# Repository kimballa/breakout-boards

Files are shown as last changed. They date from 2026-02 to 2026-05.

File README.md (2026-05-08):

SMD breakout boards
===================

This repo contains Kicad projects and camera-ready gerber files for panelized SMD component breakout boards.
The design of these breakout boards emphasizes narrow breakouts that "waste" fewer rows of pins in breadboards,
at the expense of slightly longer breakout boards that "overhang"  some number of pins to the left or right
of the actual pin header. In most cases, breakout boards are the same width as a comparable THT DIP
component. Others span the gap in the middle of a breadboard plus only a single extra row (beyond the two rows
necessary for the pin headers).

Panels are designed to fit within the 100x100 mm size for a JLCPCB economy "special price" build. In many
cases, the 5 panel minimum will still result in a supply of breakout boards that will last even ambitious
hobbyists a long while. If you require more, the low marginal cost of increasing to 10 or 20 panels likely 
outcompetes the cost of making larger panels that can be ordered at qty=5.

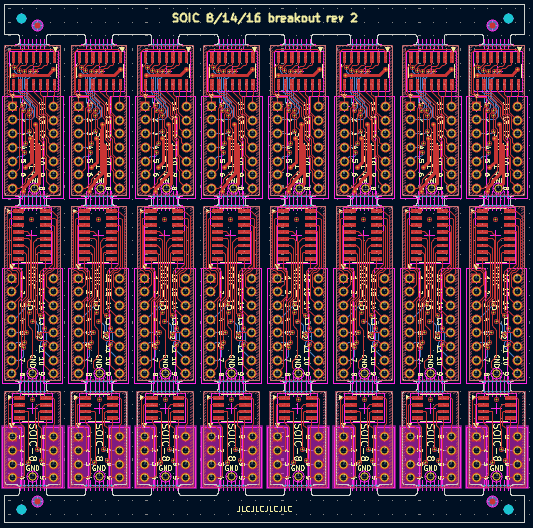
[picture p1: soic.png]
SOIC breakout board panel PCB CAD drawing SOIC breakout board panel


Directory structure
-------------------

There are a few subdirectories that each contain one or more breakout boards:

* `soic` - Two panels with a mix of SOIC-8, -14, and -16 breakouts, and TSSOP-8, -14, and -16
  breakouts.
* `soic-dw` - A panel with a mix of "widebody" (Texas Instruments drawing "DW") SOIC-16 and
  SOIC-20 breakouts
* `sot-23` - Two panels of SOT-23-6 and SOT-23-8 breakouts
* `qfn-20` - A non-panelized QFN-20 breakout board
* `so-8-fet` - Panelized SO-8 / 5050 FET / Power-TDFN footprint for SMD power MOSFETs.
  Uses NXP's "universal 5060 footprint" for maximum adaptability.
* `micromatch-20` - a separate (non-panelized) breakout for the MicroMaTcH 20 pin connector 

All panels were created with KiKit. Each "base" directory contains Kicad project and PCB layout(s)
for singleton breakout boards. Panelized PCBs are in a subdirectory called `out` or `panelized`.

* The SOT-23 and SO-8-FET breakout boards were made using the KiKit GUI from the plugin. To regenerate, load the JSON config
  file to load the appropriate settings, and identify the input kicad_pcb and target kicad_pcb files.
* The SOIC / TSSOP and SOIC-DW breakout boards were made using the KiKit API. Each directory has a script
  called `panelize.py`. Open a KiCad Command Line terminal and run `python panelize.py` in the directory.
  The output will be generated in the `out/` subdirectory. The same `panelize.py` script in the `soic` 
  directory is used for generating SOIC or TSSOP panel, but some settings at the top of the script must
  be edited to switch from one to the other.

Gerber files are available in the `rtm/` subdirectory of each subproject. If multiple subdirectories exist
within `rtm`, choose the highest-numbered version to get the latest Gerbers.

Ordering breakout panels
------------------------

Zip up the gerber (and .drl) files in a given rtm directory and upload it to JLCPCB.com. The panel size and "2 layers" 
should be auto-selected. Choose "panel by customer", input the number of unique designs in the board file
(3 for SOIC and TSSOP; 2 for SOIC-DW, 1 for SOT-23-6 and SOT-23-8), and the number of rows and columns.

You should also probably select "remove order number", and your choice of HASL or HASL Lead-free surface
finishing. (You could choose ENIG but it will be overkill, *unless you are ordering the QFN*, in which case
it is mandatory.)

The default number of each panel you order is 5; you can also dial this up as-needed. 

Assembly
--------

Arrange your SMT component on the board with pin 1 closest to the dot or triangular arrow mark on the board
in the SMT area. Tack down one pin with your soldering iron, then do the rest. Clip pin headers to length
and place them in the breadboard, then seat the breakout board on top. Solder from above, lightly pressing 
the board down onto the seating plane of the pin headers.  

Any 2.54mm-pitch pin headers will do, but if you're looking for a specific part to order, Amphenol ICC (FCI)
part number `68000-400HLF` is a quality cuttable pin header strip, orderable from Mouser, Digikey, and likely
many others. Order qty is the number of connected pins you'd like; I typically buy by the 500 or so.

Where possible, a "ground plane" is provided on many breakout boards. A separate 1.1mm hole is available
in the middle of the board. After attaching the chip and the pin headers, solder a short piece of jumper 
wire from the hole to the top of whichever pin indicates GND (likely the one in the front right corner, 
but not always; check your datasheet).

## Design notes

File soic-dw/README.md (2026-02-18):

SOIC-DW (Wide) Breakouts
========================

Breakout boards for {16, 20}-pin wide-body SOIC (1.27mm pitch) ICs that fit in standard pin
alignment on a breadboard.

The IC itself sits to the side of the pin headers rather than between them, to achieve a
narrow breakout board profile (12.8mm) that straddles only one extra row of pins on one
or the other side of the breadboard centerline.

A separate through-hole exists in the SOIC-16 board, connected to the ground plane. Solder a
resistor leg or other thin wire from the `GND` hole to top of the header pin that
represents ground for the IC. (Or leave floating if there is no appropriate ground pin for
the IC.)

The file name (SOIC-DW) derives from Texas Instruments' name for the wide SOIC package type.

## Gerber files

The latest gerber files for submitting to a board fab are in the `rtm/` directory.

If submitting to JLCPCB, select 'panel by customer', 'number of designs' = 2.

## Panelization

The main project file includes one of each representative breakout board. Panels with 8x
SOIC-16 and 6x SOIC-20 format were generated using KiKit. If you change the main PCB
CAD file, you should then open a KiCad Command Prompt in this directory and run `python
panelize.py`. You can edit `panelize.py` first to set variables related to the output file
to generate.

### Script notes:

The current layout is intended to fit in the 100x100 mm area that offers the best
deal for JLCPCB, but you can extend taller or wider if desired.

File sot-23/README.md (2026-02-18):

SOT-23 breakouts
================

This directory contains kicad project files and camera-ready gerber files for SOT-23-6 and
SOT-23-8 breakout board PCBs.

Order PCBs
----------

Look in the `panelized/rtm/` directory and select the subdirectory with the highest
version number.  There are separate subdirectories in there for SOT-23-6 and SOT-23-8
breakout boards. Take all the files in one of those subdirectories (gerber files and
Excellon drill files) and zip them together. 

Order PCBs from jlcpcb.com:
* upload the zip file
* Set PCB Qty as you desire
* Panel By Customer
  * SOT-23-6: 10 cols, 6 rows
  * SOT-23-8: 7 cols, 6 rows
* Surface Finish: HASL (with lead) or LeadFree HASL as you desire
* All other options as-default.

To adjust board layouts
-----------------------

There is a source schematic which was used to create the sot-23 (6) and sot-23-8 kicad_pcb
files.  The schematic contains both breakouts; half of this was deleted on each PCB,
leaving each kicad_pcb file with a single sot-23-6 or sot-23-8 breakout. 

The panel PCBs in the `panelized/` subdirectory were derived from these using the KiKit
panelization plugin. JSON config files for each board are in the panelized/ directory and
can be imported into the KiKit configuration dialog to reproduce the same settings used to
generate the current panels.

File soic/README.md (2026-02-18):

SOIC Breakouts
==============

Breakout boards for {8, 14, 16}-pin SOIC and TSSOP ICs
that fit in a standard DIP width on a breadboard.

The IC itself sits to the side of the pin headers rather than between them, to achieve a
narrow breakout board profile (10.3mm) that does not straddle an extra row of pins on one
or the other side of the breadboard centerline. 

A separate through-hole exists in each SOIC board, connected to the ground plane. Solder a
resistor leg or other thin wire from the `GND` hole to top of the header pin that
represents ground for the IC. (Or leave floating if there is no appropriate ground pin for
the IC.)

## Gerber files

The latest gerber files for submitting to a board fab are in the `rtm/` directory.

If submitting to JLCPCB, select 'panel by customer', 'number of designs' = 3. 

## Panelization

The main project file includes one of each representative breakout board. Panels with 8 of
each SOIC or 8 of each TSSOP format were generated using KiKit. If you change the main PCB
CAD file, you should then open a KiCad Command Prompt in this directory and run `python
panelize.py`. You can edit `panelize.py` first to set variables related to the output file
to generate. You need to edit the script to select B1-B3 (SOIC), or B4-B6 (TSSOP boards)
for panelization.

### Script notes:

The current layout (n=8) is intended to fit in the 100x100 mm area that offers the best
deal for JLCPCB, but you can extend wider. The script would need to be modified to include
more than one row of each board. The script also assumes that all boards are the same
width, and may misalign columns if not accounted-for in any future modification that
changes some of the board widths.

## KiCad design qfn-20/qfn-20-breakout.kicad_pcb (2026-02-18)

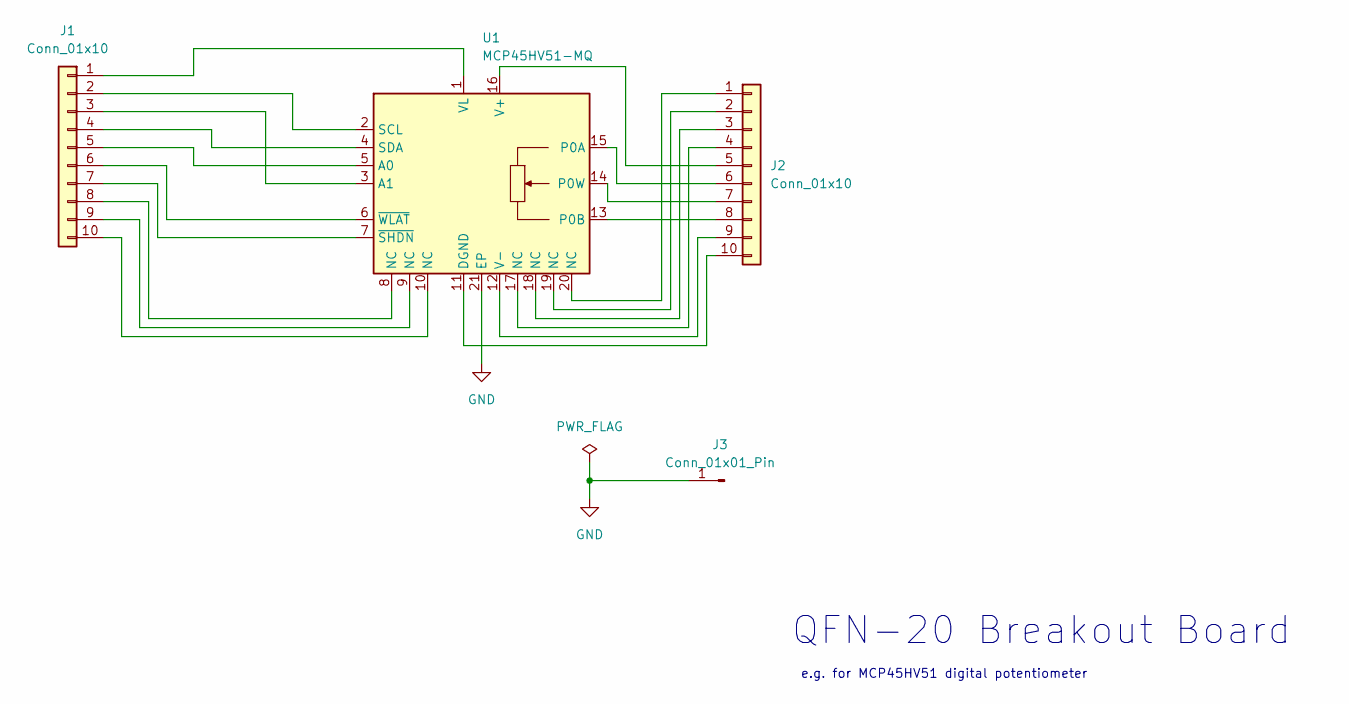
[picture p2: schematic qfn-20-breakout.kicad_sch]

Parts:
J1, J2: Conn_01x10; PinHeader_1x10_P2.54mm_Vertical
J3: Conn_01x01_Pin; TP_HeaderPin_P2.54mm_round
U1: MCP45HV51-MQ; TI-QFN-20-1EP_5x5mm_P0.65mm_EP3.35x3.35mm

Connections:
GND: J3.1, U1.21 (EP)
unnamed: J1.1, U1.1 (VL)
unnamed: J1.2, U1.2 (SCL)
unnamed: J1.3, U1.3 (A1)
unnamed: J1.4, U1.4 (SDA)
unnamed: J1.5, U1.5 (A0)
unnamed: J1.6, U1.6 (~WLAT)
unnamed: J1.7, U1.7 (~SHDN)
unnamed: J1.8, U1.8 (NC)
unnamed: J1.9, U1.9 (NC)
unnamed: J1.10, U1.10 (NC)
unnamed: J2.1, U1.20 (NC)
unnamed: J2.2, U1.19 (NC)
unnamed: J2.3, U1.18 (NC)
unnamed: J2.4, U1.17 (NC)
unnamed: J2.5, U1.16 (V+)
unnamed: J2.6, U1.15 (P0A)
unnamed: J2.7, U1.14 (P0W)
unnamed: J2.8, U1.13 (P0B)
unnamed: J2.9, U1.12 (V-)
unnamed: J2.10, U1.11 (DGND)

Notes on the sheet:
e.g. for MCP45HV51 digital potentiometer
QFN-20 Breakout Board

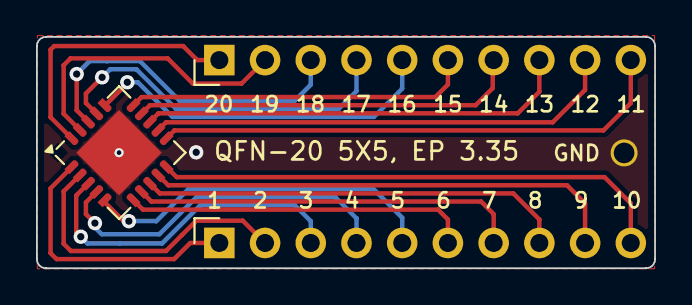
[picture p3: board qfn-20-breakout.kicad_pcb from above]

Board: 2 copper layers, 34.3 x 12.9 mm, 4 parts (0 on the bottom side), 21 nets.

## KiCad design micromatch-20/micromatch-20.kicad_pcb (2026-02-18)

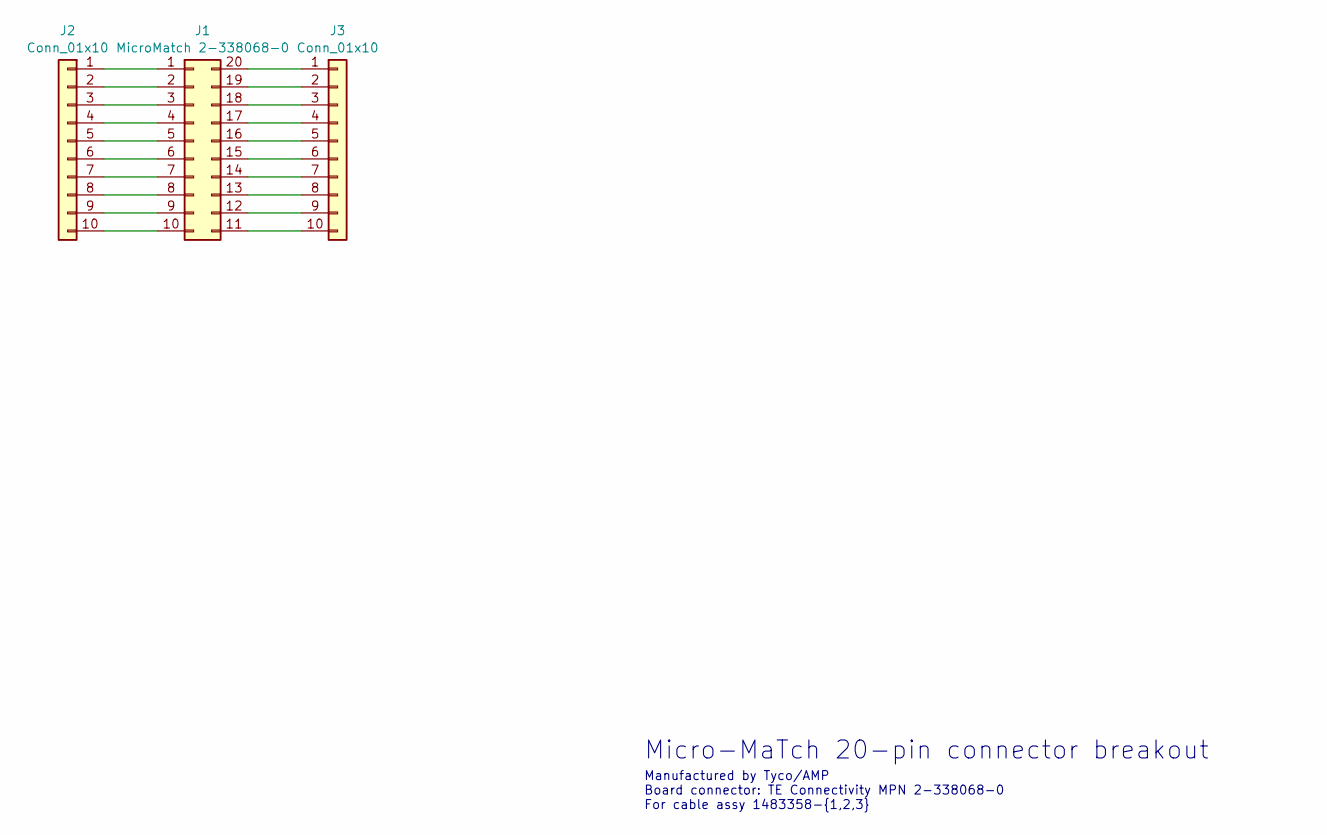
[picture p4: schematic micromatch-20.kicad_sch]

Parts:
J1: MicroMatch 2-338068-0; MicroMatch_20_F_Socket_2x10
J2, J3: Conn_01x10; PinHeader_1x10_P2.54mm_Vertical

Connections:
unnamed: J1.1, J2.1
unnamed: J1.2, J2.2
unnamed: J1.3, J2.3
unnamed: J1.4, J2.4
unnamed: J1.5, J2.5
unnamed: J1.6, J2.6
unnamed: J1.7, J2.7
unnamed: J1.8, J2.8
unnamed: J1.9, J2.9
unnamed: J1.10, J2.10
unnamed: J1.11, J3.10
unnamed: J1.12, J3.9
unnamed: J1.13, J3.8
unnamed: J1.14, J3.7
unnamed: J1.15, J3.6
unnamed: J1.16, J3.5
unnamed: J1.17, J3.4
unnamed: J1.18, J3.3
unnamed: J1.19, J3.2
unnamed: J1.20, J3.1

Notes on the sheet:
Micro-MaTch 20-pin connector breakout
Manufactured by Tyco/AMP Board connector: TE Connectivity MPN 2-338068-0 For cable assy 1483358-{1,2,3}

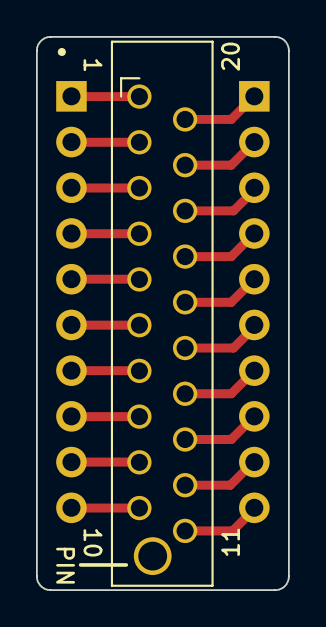
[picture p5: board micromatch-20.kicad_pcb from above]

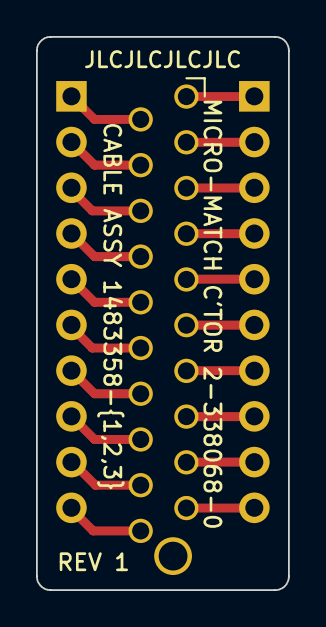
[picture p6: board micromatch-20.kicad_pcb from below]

Board: 2 copper layers, 14.0 x 30.7 mm, 3 parts (2 on the bottom side), 20 nets.

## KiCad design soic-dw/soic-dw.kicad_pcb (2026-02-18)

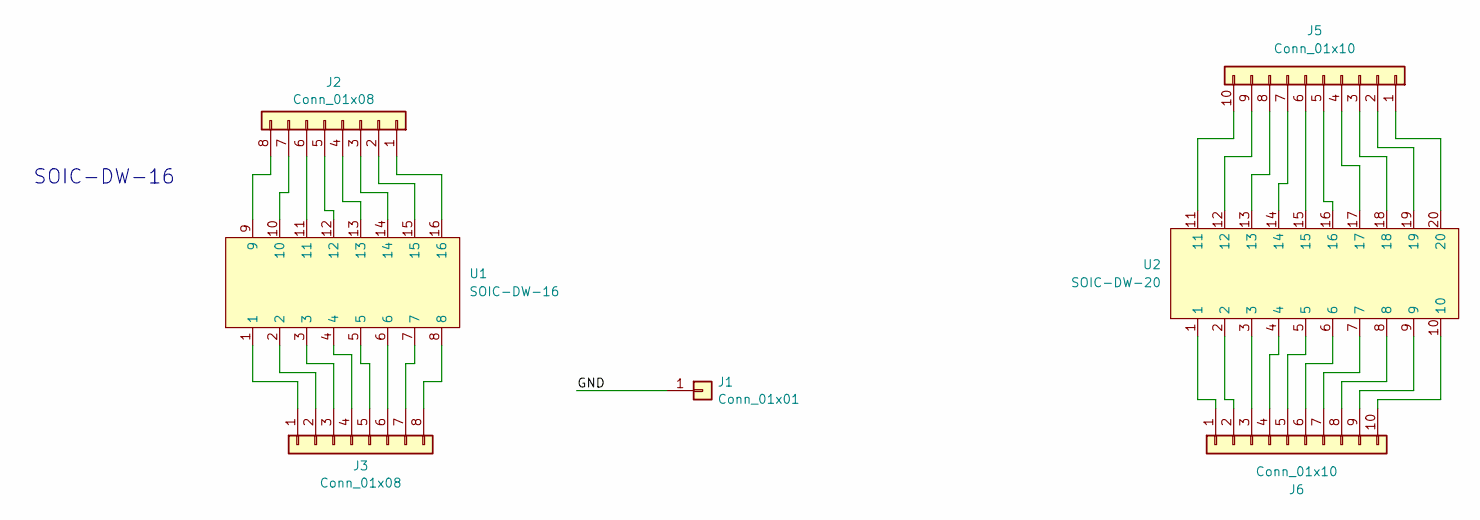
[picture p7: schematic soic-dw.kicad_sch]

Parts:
J1: Conn_01x01; TP_HeaderPin_P2.54mm_round
J2, J3: Conn_01x08; PinHeader_1x08_P2.54mm_Vertical
J5, J6: Conn_01x10; PinHeader_1x10_P2.54mm_Vertical
U1: SOIC-DW-16; TI_SOIC_DW0016A_MinSilk
U2: SOIC-DW-20; TI_SOIC_DW0020A

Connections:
/GND: J1.1
unnamed: J2.1, U1.16
unnamed: J2.2, U1.15
unnamed: J2.3, U1.14
unnamed: J2.4, U1.13
unnamed: J2.5, U1.12
unnamed: J2.6, U1.11
unnamed: J2.7, U1.10
unnamed: J2.8, U1.9
unnamed: J3.1, U1.1
unnamed: J3.2, U1.2
unnamed: J3.3, U1.3
unnamed: J3.4, U1.4
unnamed: J3.5, U1.5
unnamed: J3.6, U1.6
unnamed: J3.7, U1.7
unnamed: J3.8, U1.8
unnamed: J5.1, U2.20
unnamed: J5.2, U2.19
unnamed: J5.3, U2.18
unnamed: J5.4, U2.17
unnamed: J5.5, U2.16
unnamed: J5.6, U2.15
unnamed: J5.7, U2.14
unnamed: J5.8, U2.13
unnamed: J5.9, U2.12
unnamed: J5.10, U2.11
unnamed: J6.1, U2.1
unnamed: J6.2, U2.2
unnamed: J6.3, U2.3
unnamed: J6.4, U2.4
unnamed: J6.5, U2.5
unnamed: J6.6, U2.6
unnamed: J6.7, U2.7
unnamed: J6.8, U2.8
unnamed: J6.9, U2.9
unnamed: J6.10, U2.10

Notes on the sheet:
SOIC-DW-16

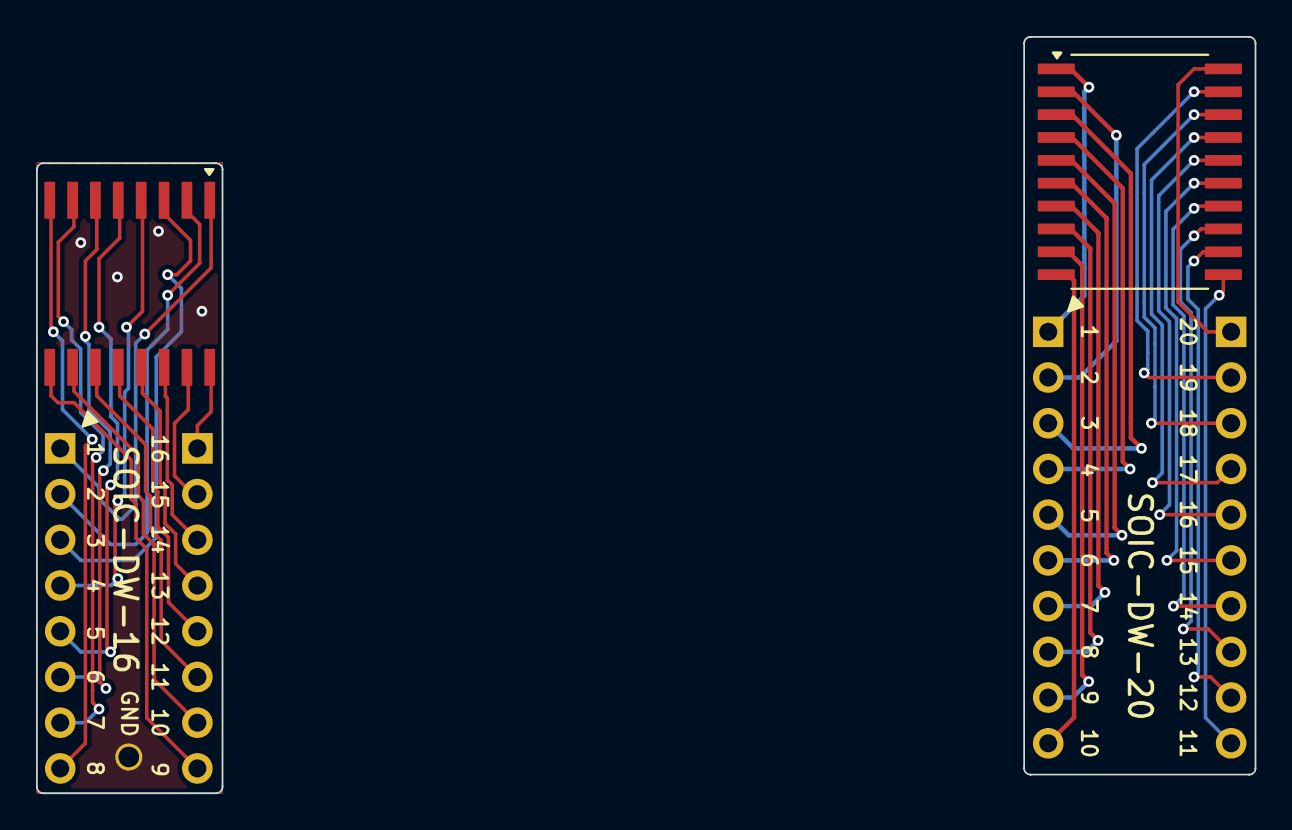
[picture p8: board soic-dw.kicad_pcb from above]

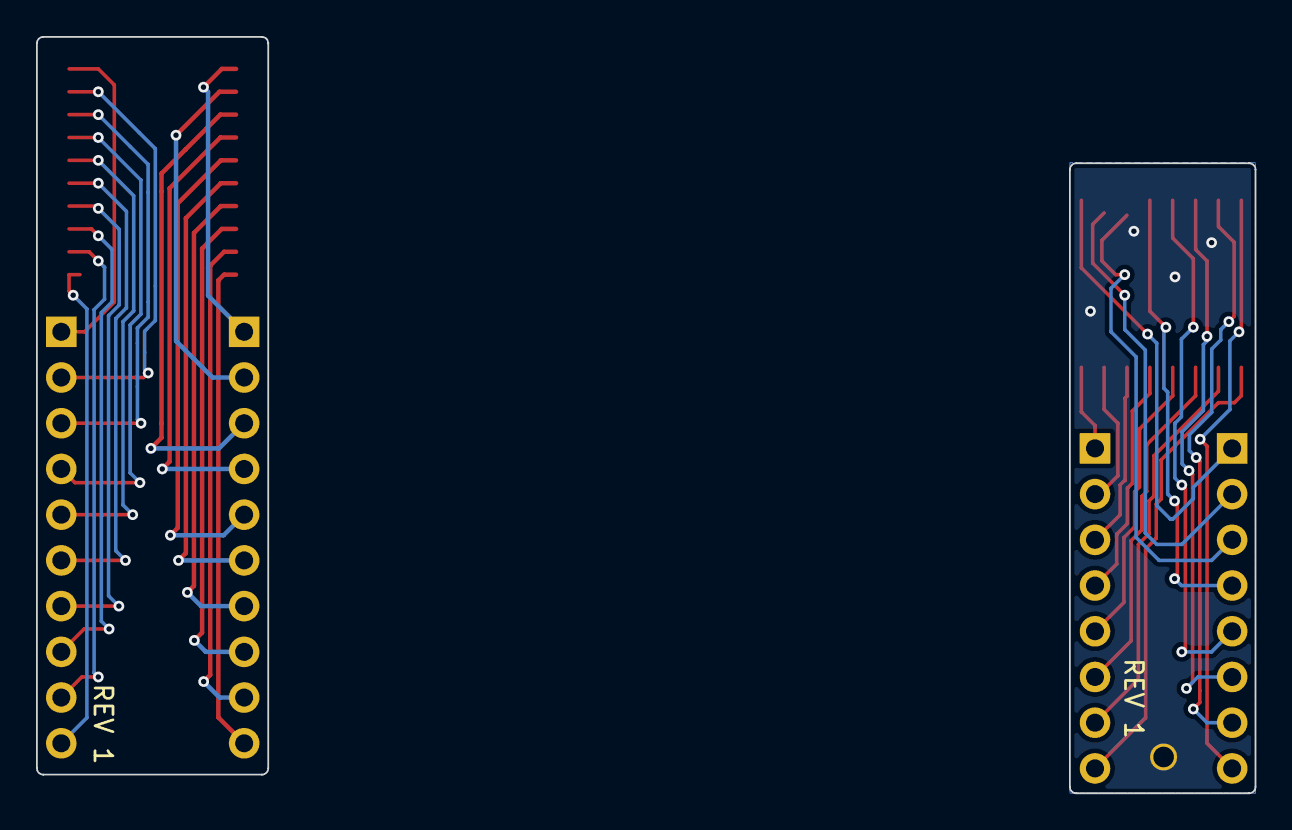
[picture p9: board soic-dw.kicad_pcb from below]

Board: 2 copper layers, 67.7 x 42.0 mm, 9 parts (4 on the bottom side), 36 nets.

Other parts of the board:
B1, B2: Board

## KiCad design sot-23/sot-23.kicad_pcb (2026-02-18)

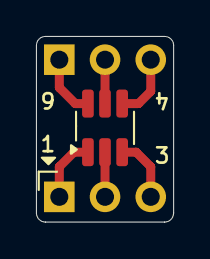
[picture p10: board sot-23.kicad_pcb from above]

Board: 2 copper layers, 7.6 x 10.3 mm, 3 parts (0 on the bottom side), 6 nets.

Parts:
J1, J2: Conn_01x03; PinHeader_1x03_P2.54mm_Vertical
Q1: BCM847DS; SOT-23-6_Handsoldering

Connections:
unnamed: J1.1, Q1.1 (E1)
unnamed: J1.2, Q1.2 (B1)
unnamed: J1.3, Q1.3 (C2)
unnamed: J2.1, Q1.6 (C1)
unnamed: J2.2, Q1.5 (B2)
unnamed: J2.3, Q1.4 (E2)

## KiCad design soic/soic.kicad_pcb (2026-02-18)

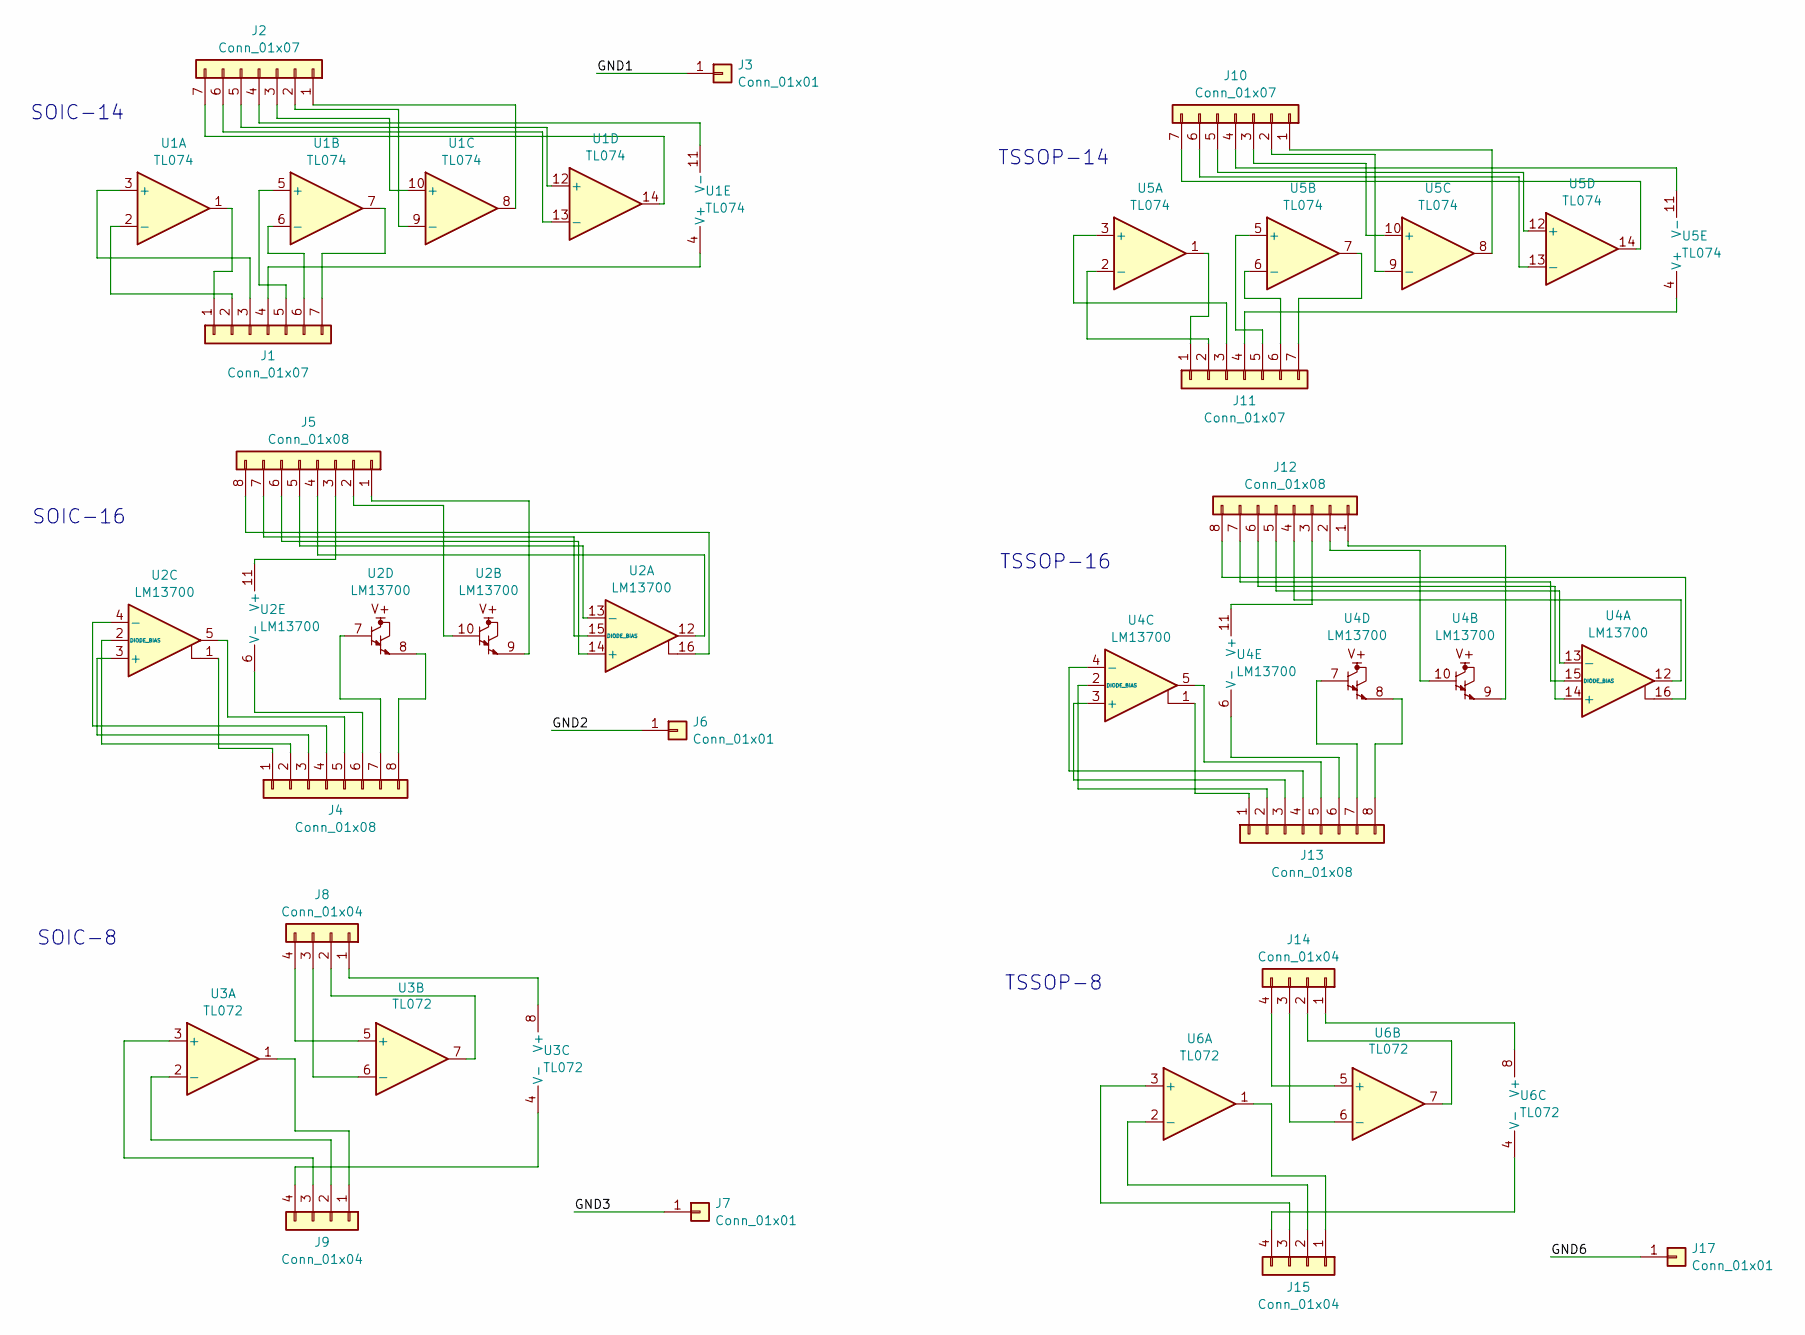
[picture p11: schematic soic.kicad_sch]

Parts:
J1, J2, J10, J11: Conn_01x07; PinHeader_1x07_P2.54mm_Vertical
J3, J6, J7, J17: Conn_01x01; TP_HeaderPin_P2.54mm_round
J4, J5, J12, J13: Conn_01x08; PinHeader_1x08_P2.54mm_Vertical
J8, J9, J14, J15: Conn_01x04; PinHeader_1x04_P2.54mm_Vertical
U1: TL074; TI_SOIC_D_R-PDSO-G14
U2: LM13700; TI_SOIC_D_R-PDSO-16
U3: TL072; TI_SOIC_D_R-PDSO-8
U4: LM13700; TSSOP-16_4.4x5mm_P0.65mm
U5: TL074; TI_TSSOP_PW0014A
U6: TL072; TI_TSSOP_PW0008A

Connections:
/GND1: J3.1
/GND2: J6.1
/GND3: J7.1
/GND6: J17.1
unnamed: J1.1, U1.1
unnamed: J1.2, U1.2 (-)
unnamed: J1.3, U1.3 (+)
unnamed: J1.4, U1.4 (V+)
unnamed: J1.5, U1.5 (+)
unnamed: J1.6, U1.6 (-)
unnamed: J1.7, U1.7
unnamed: J2.1, U1.8
unnamed: J2.2, U1.9 (-)
unnamed: J2.3, U1.10 (+)
unnamed: J2.4, U1.11 (V-)
unnamed: J2.5, U1.12 (+)
unnamed: J2.6, U1.13 (-)
unnamed: J2.7, U1.14
unnamed: J4.1, U2.1
unnamed: J4.2, U2.2 (DIODE_BIAS)
unnamed: J4.3, U2.3 (+)
unnamed: J4.4, U2.4 (-)
unnamed: J4.5, U2.5
unnamed: J4.6, U2.6 (V-)
unnamed: J4.7, U2.7
unnamed: J4.8, U2.8
unnamed: J5.1, U2.9
unnamed: J5.2, U2.10
unnamed: J5.3, U2.11 (V+)
unnamed: J5.4, U2.12
unnamed: J5.5, U2.13 (-)
unnamed: J5.6, U2.14 (+)
unnamed: J5.7, U2.15 (DIODE_BIAS)
unnamed: J5.8, U2.16
unnamed: J8.1, U3.8 (V+)
unnamed: J8.2, U3.7
unnamed: J8.3, U3.6 (-)
unnamed: J8.4, U3.5 (+)
unnamed: J9.1, U3.1
unnamed: J9.2, U3.2 (-)
unnamed: J9.3, U3.3 (+)
unnamed: J9.4, U3.4 (V-)
unnamed: J10.1, U5.8
unnamed: J10.2, U5.9 (-)
unnamed: J10.3, U5.10 (+)
unnamed: J10.4, U5.11 (V-)
unnamed: J10.5, U5.12 (+)
unnamed: J10.6, U5.13 (-)
unnamed: J10.7, U5.14
unnamed: J11.1, U5.1
unnamed: J11.2, U5.2 (-)
unnamed: J11.3, U5.3 (+)
unnamed: J11.4, U5.4 (V+)
unnamed: J11.5, U5.5 (+)
unnamed: J11.6, U5.6 (-)
unnamed: J11.7, U5.7
unnamed: J12.1, U4.9
unnamed: J12.2, U4.10
unnamed: J12.3, U4.11 (V+)
unnamed: J12.4, U4.12
unnamed: J12.5, U4.13 (-)
unnamed: J12.6, U4.14 (+)
unnamed: J12.7, U4.15 (DIODE_BIAS)
unnamed: J12.8, U4.16
unnamed: J13.1, U4.1
unnamed: J13.2, U4.2 (DIODE_BIAS)
unnamed: J13.3, U4.3 (+)
unnamed: J13.4, U4.4 (-)
unnamed: J13.5, U4.5
unnamed: J13.6, U4.6 (V-)
unnamed: J13.7, U4.7
unnamed: J13.8, U4.8
unnamed: J14.1, U6.8 (V+)
unnamed: J14.2, U6.7
unnamed: J14.3, U6.6 (-)
unnamed: J14.4, U6.5 (+)
unnamed: J15.1, U6.1
unnamed: J15.2, U6.2 (-)
unnamed: J15.3, U6.3 (+)
unnamed: J15.4, U6.4 (V-)

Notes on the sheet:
SOIC-14
TSSOP-8
SOIC-8
TSSOP-14
SOIC-16
TSSOP-16

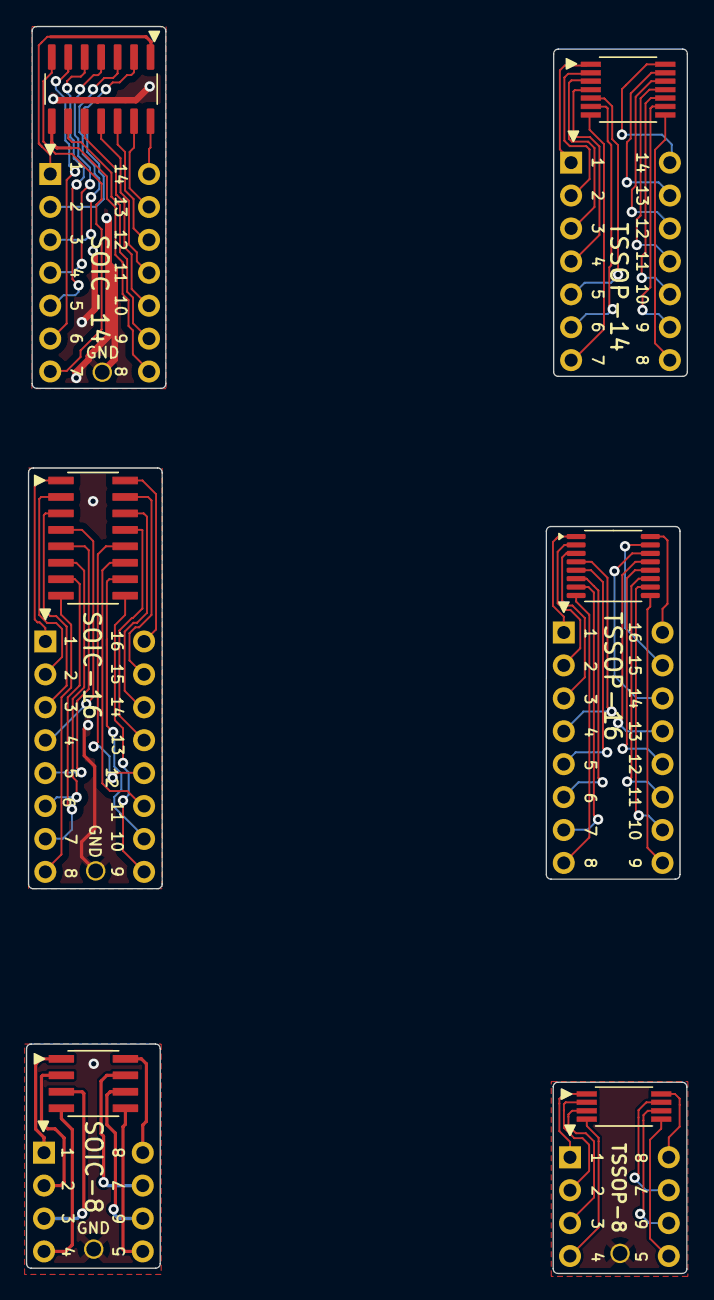
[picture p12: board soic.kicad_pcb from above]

Board: 2 copper layers, 51.0 x 96.2 mm, 28 parts (0 on the bottom side), 76 nets.

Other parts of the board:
B1, B2, B3, B4, B5, B6: Board

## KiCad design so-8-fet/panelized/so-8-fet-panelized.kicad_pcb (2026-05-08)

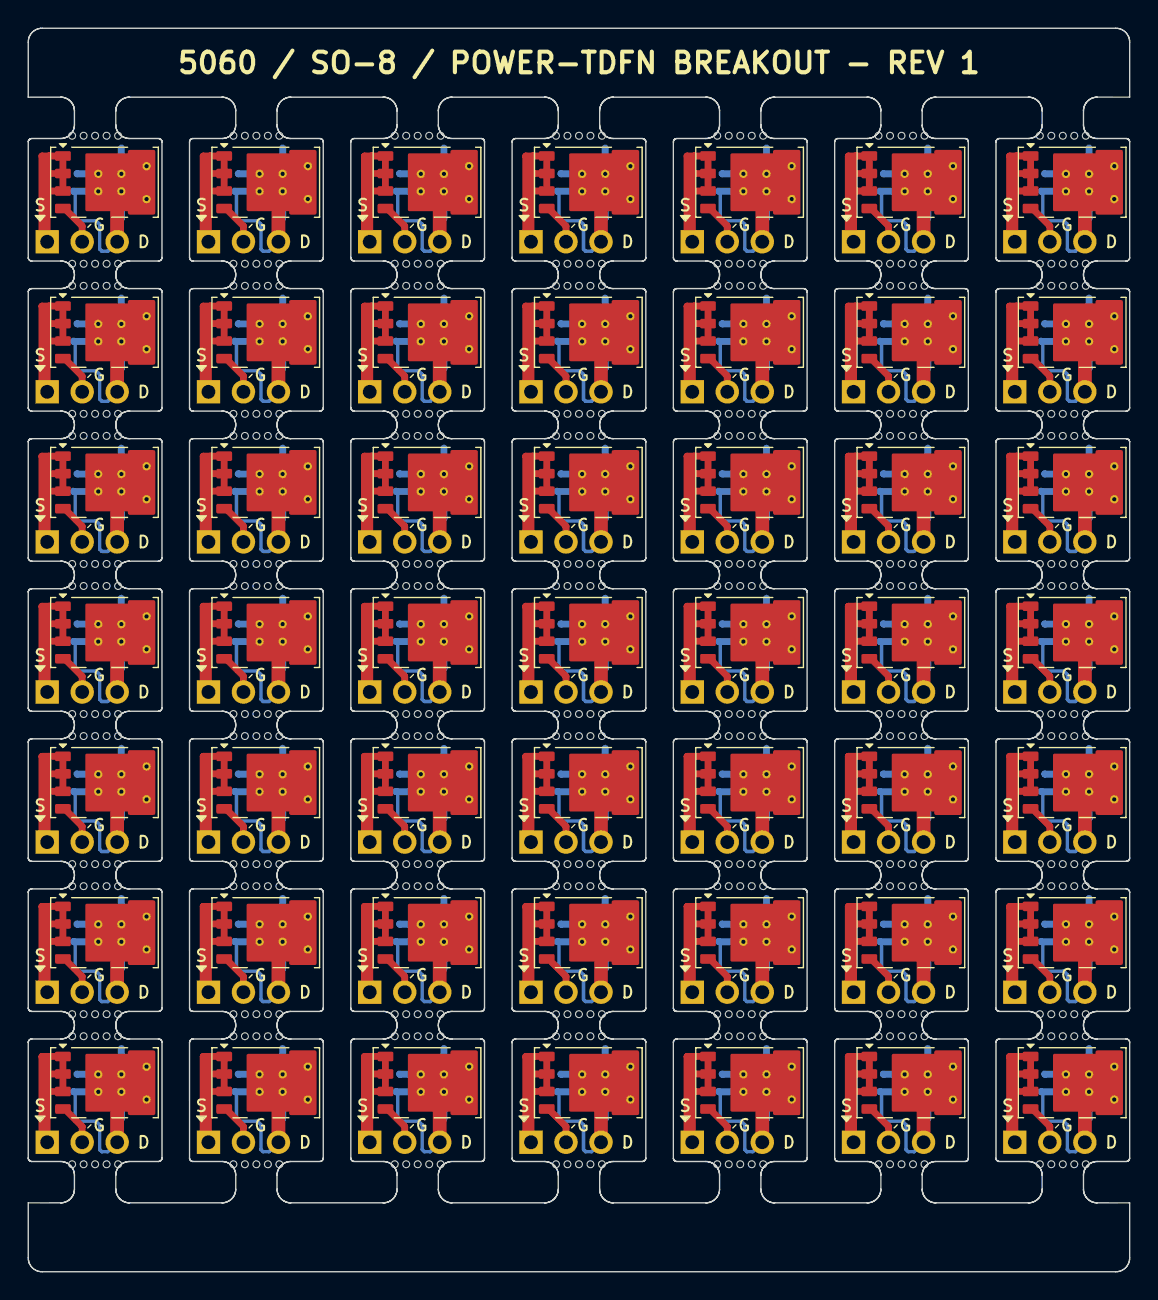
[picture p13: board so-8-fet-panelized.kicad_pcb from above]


Board: 2 copper layers, 79.9 x 90.2 mm, 588 parts (49 on the bottom side), 147 nets.

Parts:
J1, J1#2, J1#3, J1#4, J1#5, J1#6, J1#7, J1#8, J1#9, J1#10, J1#11, J1#12, J1#13, J1#14, J1#15, J1#16, J1#17, J1#18, J1#19, J1#20, J1#21, J1#22, J1#23, J1#24, J1#25, J1#26, J1#27, J1#28, J1#29, J1#30, J1#31, J1#32, J1#33, J1#34, J1#35, J1#36, J1#37, J1#38, J1#39, J1#40, J1#41, J1#42, J1#43, J1#44, J1#45, J1#46, J1#47, J1#48, J1#49: Conn_01x03; PinHeader_1x03_P2.54mm_Vertical
KiKit_MB_1_2, KiKit_MB_1_3, KiKit_MB_1_4, KiKit_MB_1_5, KiKit_MB_1_6, KiKit_MB_2_2, KiKit_MB_2_3, KiKit_MB_2_4, KiKit_MB_2_5, KiKit_MB_2_6, KiKit_MB_3_2, KiKit_MB_3_3, KiKit_MB_3_4, KiKit_MB_3_5, KiKit_MB_3_6, KiKit_MB_4_2, KiKit_MB_4_3, KiKit_MB_4_4, KiKit_MB_4_5, KiKit_MB_4_6, KiKit_MB_5_2, KiKit_MB_5_3, KiKit_MB_5_4, KiKit_MB_5_5, KiKit_MB_5_6, KiKit_MB_6_2, KiKit_MB_6_3, KiKit_MB_6_4, KiKit_MB_6_5, KiKit_MB_6_6, KiKit_MB_7_2, KiKit_MB_7_3, KiKit_MB_7_4, KiKit_MB_7_5, KiKit_MB_7_6, KiKit_MB_8_2, KiKit_MB_8_3, KiKit_MB_8_4, KiKit_MB_8_5, KiKit_MB_8_6, KiKit_MB_9_2, KiKit_MB_9_3, KiKit_MB_9_4, KiKit_MB_9_5, KiKit_MB_9_6, KiKit_MB_10_2, KiKit_MB_10_3, KiKit_MB_10_4, KiKit_MB_10_5, KiKit_MB_10_6, KiKit_MB_11_2, KiKit_MB_11_3, KiKit_MB_11_4, KiKit_MB_11_5, KiKit_MB_11_6, KiKit_MB_12_2, KiKit_MB_12_3, KiKit_MB_12_4, KiKit_MB_12_5, KiKit_MB_12_6, KiKit_MB_13_2, KiKit_MB_13_3, KiKit_MB_13_4, KiKit_MB_13_5, KiKit_MB_13_6, KiKit_MB_14_2, KiKit_MB_14_3, KiKit_MB_14_4, KiKit_MB_14_5, KiKit_MB_14_6, KiKit_MB_15_2, KiKit_MB_15_3, KiKit_MB_15_4, KiKit_MB_15_5, KiKit_MB_15_6, KiKit_MB_16_2, KiKit_MB_16_3, KiKit_MB_16_4, KiKit_MB_16_5, KiKit_MB_16_6, KiKit_MB_17_2, KiKit_MB_17_3, KiKit_MB_17_4, KiKit_MB_17_5, KiKit_MB_17_6, KiKit_MB_18_2, KiKit_MB_18_3, KiKit_MB_18_4, KiKit_MB_18_5, KiKit_MB_18_6, KiKit_MB_19_2, KiKit_MB_19_3, KiKit_MB_19_4, KiKit_MB_19_5, KiKit_MB_19_6, KiKit_MB_20_2, KiKit_MB_20_3, KiKit_MB_20_4, KiKit_MB_20_5, KiKit_MB_20_6, KiKit_MB_21_2, KiKit_MB_21_3, KiKit_MB_21_4, KiKit_MB_21_5, KiKit_MB_21_6, KiKit_MB_22_2, KiKit_MB_22_3, KiKit_MB_22_4, KiKit_MB_22_5, KiKit_MB_22_6, KiKit_MB_23_2, KiKit_MB_23_3, KiKit_MB_23_4, KiKit_MB_23_5, KiKit_MB_23_6, KiKit_MB_24_2, KiKit_MB_24_3, KiKit_MB_24_4, KiKit_MB_24_5, KiKit_MB_24_6, KiKit_MB_25_2, KiKit_MB_25_3, KiKit_MB_25_4, KiKit_MB_25_5, KiKit_MB_25_6, KiKit_MB_26_2, KiKit_MB_26_3, KiKit_MB_26_4, KiKit_MB_26_5, KiKit_MB_26_6, KiKit_MB_27_2, KiKit_MB_27_3, KiKit_MB_27_4, KiKit_MB_27_5, KiKit_MB_27_6, KiKit_MB_28_2, KiKit_MB_28_3, KiKit_MB_28_4, KiKit_MB_28_5, KiKit_MB_28_6, KiKit_MB_29_2, KiKit_MB_29_3, KiKit_MB_29_4, KiKit_MB_29_5, KiKit_MB_29_6, KiKit_MB_30_2, KiKit_MB_30_3, KiKit_MB_30_4, KiKit_MB_30_5, KiKit_MB_30_6, KiKit_MB_31_2, KiKit_MB_31_3, KiKit_MB_31_4, KiKit_MB_31_5, KiKit_MB_31_6, KiKit_MB_32_2, KiKit_MB_32_3, KiKit_MB_32_4, KiKit_MB_32_5, KiKit_MB_32_6, KiKit_MB_33_2, KiKit_MB_33_3, KiKit_MB_33_4, KiKit_MB_33_5, KiKit_MB_33_6, KiKit_MB_34_2, KiKit_MB_34_3, KiKit_MB_34_4, KiKit_MB_34_5, KiKit_MB_34_6, KiKit_MB_35_2, KiKit_MB_35_3, KiKit_MB_35_4, KiKit_MB_35_5, KiKit_MB_35_6, KiKit_MB_36_2, KiKit_MB_36_3, KiKit_MB_36_4, KiKit_MB_36_5, KiKit_MB_36_6, KiKit_MB_37_2, KiKit_MB_37_3, KiKit_MB_37_4, KiKit_MB_37_5, KiKit_MB_37_6, KiKit_MB_38_2, KiKit_MB_38_3, KiKit_MB_38_4, KiKit_MB_38_5, KiKit_MB_38_6, KiKit_MB_39_2, KiKit_MB_39_3, KiKit_MB_39_4, KiKit_MB_39_5, KiKit_MB_39_6, KiKit_MB_40_2, KiKit_MB_40_3, KiKit_MB_40_4, KiKit_MB_40_5, KiKit_MB_40_6, KiKit_MB_41_2, KiKit_MB_41_3, KiKit_MB_41_4, KiKit_MB_41_5, KiKit_MB_41_6, KiKit_MB_42_2, KiKit_MB_42_3, KiKit_MB_42_4, KiKit_MB_42_5, KiKit_MB_42_6, KiKit_MB_43_2, KiKit_MB_43_3, KiKit_MB_43_4, KiKit_MB_43_5, KiKit_MB_43_6, KiKit_MB_44_2, KiKit_MB_44_3, KiKit_MB_44_4, KiKit_MB_44_5, KiKit_MB_44_6, KiKit_MB_45_2, KiKit_MB_45_3, KiKit_MB_45_4, KiKit_MB_45_5, KiKit_MB_45_6, KiKit_MB_46_2, KiKit_MB_46_3, KiKit_MB_46_4, KiKit_MB_46_5, KiKit_MB_46_6, KiKit_MB_47_2, KiKit_MB_47_3, KiKit_MB_47_4, KiKit_MB_47_5, KiKit_MB_47_6, KiKit_MB_48_2, KiKit_MB_48_3, KiKit_MB_48_4, KiKit_MB_48_5, KiKit_MB_48_6, KiKit_MB_49_2, KiKit_MB_49_3, KiKit_MB_49_4, KiKit_MB_49_5, KiKit_MB_49_6, KiKit_MB_50_2, KiKit_MB_50_3, KiKit_MB_50_4, KiKit_MB_50_5, KiKit_MB_50_6, KiKit_MB_51_2, KiKit_MB_51_3, KiKit_MB_51_4, KiKit_MB_51_5, KiKit_MB_51_6, KiKit_MB_52_2, KiKit_MB_52_3, KiKit_MB_52_4, KiKit_MB_52_5, KiKit_MB_52_6, KiKit_MB_53_2, KiKit_MB_53_3, KiKit_MB_53_4, KiKit_MB_53_5, KiKit_MB_53_6, KiKit_MB_54_2, KiKit_MB_54_3, KiKit_MB_54_4, KiKit_MB_54_5, KiKit_MB_54_6, KiKit_MB_55_2, KiKit_MB_55_3, KiKit_MB_55_4, KiKit_MB_55_5, KiKit_MB_55_6, KiKit_MB_56_2, KiKit_MB_56_3, KiKit_MB_56_4, KiKit_MB_56_5, KiKit_MB_56_6, KiKit_MB_57_2, KiKit_MB_57_3, KiKit_MB_57_4, KiKit_MB_57_5, KiKit_MB_57_6, KiKit_MB_58_2, KiKit_MB_58_3, KiKit_MB_58_4, KiKit_MB_58_5, KiKit_MB_58_6, KiKit_MB_59_2, KiKit_MB_59_3, KiKit_MB_59_4, KiKit_MB_59_5, KiKit_MB_59_6, KiKit_MB_60_2, KiKit_MB_60_3, KiKit_MB_60_4, KiKit_MB_60_5, KiKit_MB_60_6, KiKit_MB_61_2, KiKit_MB_61_3, KiKit_MB_61_4, KiKit_MB_61_5, KiKit_MB_61_6, KiKit_MB_62_2, KiKit_MB_62_3, KiKit_MB_62_4, KiKit_MB_62_5, KiKit_MB_62_6, KiKit_MB_63_2, KiKit_MB_63_3, KiKit_MB_63_4, KiKit_MB_63_5, KiKit_MB_63_6, KiKit_MB_64_2, KiKit_MB_64_3, KiKit_MB_64_4, KiKit_MB_64_5, KiKit_MB_64_6, KiKit_MB_65_2, KiKit_MB_65_3, KiKit_MB_65_4, KiKit_MB_65_5, KiKit_MB_65_6, KiKit_MB_66_2, KiKit_MB_66_3, KiKit_MB_66_4, KiKit_MB_66_5, KiKit_MB_66_6, KiKit_MB_67_2, KiKit_MB_67_3, KiKit_MB_67_4, KiKit_MB_67_5, KiKit_MB_67_6, KiKit_MB_68_2, KiKit_MB_68_3, KiKit_MB_68_4, KiKit_MB_68_5, KiKit_MB_68_6, KiKit_MB_69_2, KiKit_MB_69_3, KiKit_MB_69_4, KiKit_MB_69_5, KiKit_MB_69_6, KiKit_MB_70_2, KiKit_MB_70_3, KiKit_MB_70_4, KiKit_MB_70_5, KiKit_MB_70_6, KiKit_MB_71_2, KiKit_MB_71_3, KiKit_MB_71_4, KiKit_MB_71_5, KiKit_MB_71_6, KiKit_MB_72_2, KiKit_MB_72_3, KiKit_MB_72_4, KiKit_MB_72_5, KiKit_MB_72_6, KiKit_MB_73_2, KiKit_MB_73_3, KiKit_MB_73_4, KiKit_MB_73_5, KiKit_MB_73_6, KiKit_MB_74_2, KiKit_MB_74_3, KiKit_MB_74_4, KiKit_MB_74_5, KiKit_MB_74_6, KiKit_MB_75_2, KiKit_MB_75_3, KiKit_MB_75_4, KiKit_MB_75_5, KiKit_MB_75_6, KiKit_MB_76_2, KiKit_MB_76_3, KiKit_MB_76_4, KiKit_MB_76_5, KiKit_MB_76_6, KiKit_MB_77_2, KiKit_MB_77_3, KiKit_MB_77_4, KiKit_MB_77_5, KiKit_MB_77_6, KiKit_MB_78_2, KiKit_MB_78_3, KiKit_MB_78_4, KiKit_MB_78_5, KiKit_MB_78_6, KiKit_MB_79_2, KiKit_MB_79_3, KiKit_MB_79_4, KiKit_MB_79_5, KiKit_MB_79_6, KiKit_MB_80_2, KiKit_MB_80_3, KiKit_MB_80_4, KiKit_MB_80_5, KiKit_MB_80_6, KiKit_MB_81_2, KiKit_MB_81_3, KiKit_MB_81_4, KiKit_MB_81_5, KiKit_MB_81_6, KiKit_MB_82_2, KiKit_MB_82_3, KiKit_MB_82_4, KiKit_MB_82_5, KiKit_MB_82_6, KiKit_MB_83_2, KiKit_MB_83_3, KiKit_MB_83_4, KiKit_MB_83_5, KiKit_MB_83_6, KiKit_MB_84_2, KiKit_MB_84_3, KiKit_MB_84_4, KiKit_MB_84_5, KiKit_MB_84_6, KiKit_MB_85_2, KiKit_MB_85_3, KiKit_MB_85_4, KiKit_MB_85_5, KiKit_MB_85_6, KiKit_MB_86_2, KiKit_MB_86_3, KiKit_MB_86_4, KiKit_MB_86_5, KiKit_MB_86_6, KiKit_MB_87_2, KiKit_MB_87_3, KiKit_MB_87_4, KiKit_MB_87_5, KiKit_MB_87_6, KiKit_MB_88_2, KiKit_MB_88_3, KiKit_MB_88_4, KiKit_MB_88_5, KiKit_MB_88_6, KiKit_MB_89_2, KiKit_MB_89_3, KiKit_MB_89_4, KiKit_MB_89_5, KiKit_MB_89_6, KiKit_MB_90_2, KiKit_MB_90_3, KiKit_MB_90_4, KiKit_MB_90_5, KiKit_MB_90_6, KiKit_MB_91_2, KiKit_MB_91_3, KiKit_MB_91_4, KiKit_MB_91_5, KiKit_MB_91_6, KiKit_MB_92_2, KiKit_MB_92_3, KiKit_MB_92_4, KiKit_MB_92_5, KiKit_MB_92_6, KiKit_MB_93_2, KiKit_MB_93_3, KiKit_MB_93_4, KiKit_MB_93_5, KiKit_MB_93_6, KiKit_MB_94_2, KiKit_MB_94_3, KiKit_MB_94_4, KiKit_MB_94_5, KiKit_MB_94_6, KiKit_MB_95_2, KiKit_MB_95_3, KiKit_MB_95_4, KiKit_MB_95_5, KiKit_MB_95_6, KiKit_MB_96_2, KiKit_MB_96_3, KiKit_MB_96_4, KiKit_MB_96_5, KiKit_MB_96_6, KiKit_MB_97_2, KiKit_MB_97_3, KiKit_MB_97_4, KiKit_MB_97_5, KiKit_MB_97_6, KiKit_MB_98_2, KiKit_MB_98_3, KiKit_MB_98_4, KiKit_MB_98_5, KiKit_MB_98_6: NPTH
Q1, Q1#2, Q1#3, Q1#4, Q1#5, Q1#6, Q1#7, Q1#8, Q1#9, Q1#10, Q1#11, Q1#12, Q1#13, Q1#14, Q1#15, Q1#16, Q1#17, Q1#18, Q1#19, Q1#20, Q1#21, Q1#22, Q1#23, Q1#24, Q1#25, Q1#26, Q1#27, Q1#28, Q1#29, Q1#30, Q1#31, Q1#32, Q1#33, Q1#34, Q1#35, Q1#36, Q1#37, Q1#38, Q1#39, Q1#40, Q1#41, Q1#42, Q1#43, Q1#44, Q1#45, Q1#46, Q1#47, Q1#48, Q1#49: Q_NMOS_SSSGD_AvalancheRated; SO8_PowerTDFN_5x6_NXP_Universal_ThermalVias

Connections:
Board_0-/DRAIN: J1#33.3, Q1#29.5 (D)
Board_0-/GATE: J1#33.2, Q1#29.4 (G)
Board_0-/SRC: J1#33.1, Q1#29.1 (S), Q1#29.2 (S), Q1#29.3 (S)
Board_1-/DRAIN: J1#4.3, Q1#32.5 (D)
Board_1-/GATE: J1#4.2, Q1#32.4 (G)
Board_1-/SRC: J1#4.1, Q1#32.1 (S), Q1#32.2 (S), Q1#32.3 (S)
Board_2-/DRAIN: J1#30.3, Q1#39.5 (D)
Board_2-/GATE: J1#30.2, Q1#39.4 (G)
Board_2-/SRC: J1#30.1, Q1#39.1 (S), Q1#39.2 (S), Q1#39.3 (S)
Board_3-/DRAIN: J1#46.3, Q1#45.5 (D)
Board_3-/GATE: J1#46.2, Q1#45.4 (G)
Board_3-/SRC: J1#46.1, Q1#45.1 (S), Q1#45.2 (S), Q1#45.3 (S)
Board_4-/DRAIN: J1#20.3, Q1#31.5 (D)
Board_4-/GATE: J1#20.2, Q1#31.4 (G)
Board_4-/SRC: J1#20.1, Q1#31.1 (S), Q1#31.2 (S), Q1#31.3 (S)
Board_5-/DRAIN: J1#11.3, Q1#48.5 (D)
Board_5-/GATE: J1#11.2, Q1#48.4 (G)
Board_5-/SRC: J1#11.1, Q1#48.1 (S), Q1#48.2 (S), Q1#48.3 (S)
Board_6-/DRAIN: J1#7.3, Q1#35.5 (D)
Board_6-/GATE: J1#7.2, Q1#35.4 (G)
Board_6-/SRC: J1#7.1, Q1#35.1 (S), Q1#35.2 (S), Q1#35.3 (S)
Board_7-/DRAIN: J1#40.3, Q1#41.5 (D)
Board_7-/GATE: J1#40.2, Q1#41.4 (G)
Board_7-/SRC: J1#40.1, Q1#41.1 (S), Q1#41.2 (S), Q1#41.3 (S)
Board_8-/DRAIN: J1#10.3, Q1#6.5 (D)
Board_8-/GATE: J1#10.2, Q1#6.4 (G)
Board_8-/SRC: J1#10.1, Q1#6.1 (S), Q1#6.2 (S), Q1#6.3 (S)
Board_9-/DRAIN: J1#28.3, Q1#5.5 (D)
Board_9-/GATE: J1#28.2, Q1#5.4 (G)
Board_9-/SRC: J1#28.1, Q1#5.1 (S), Q1#5.2 (S), Q1#5.3 (S)
Board_10-/DRAIN: J1#45.3, Q1#21.5 (D)
Board_10-/GATE: J1#45.2, Q1#21.4 (G)
Board_10-/SRC: J1#45.1, Q1#21.1 (S), Q1#21.2 (S), Q1#21.3 (S)
Board_11-/DRAIN: J1#31.3, Q1#23.5 (D)
Board_11-/GATE: J1#31.2, Q1#23.4 (G)
Board_11-/SRC: J1#31.1, Q1#23.1 (S), Q1#23.2 (S), Q1#23.3 (S)
Board_12-/DRAIN: J1#29.3, Q1#12.5 (D)
Board_12-/GATE: J1#29.2, Q1#12.4 (G)
Board_12-/SRC: J1#29.1, Q1#12.1 (S), Q1#12.2 (S), Q1#12.3 (S)
Board_13-/DRAIN: J1#41.3, Q1#20.5 (D)
Board_13-/GATE: J1#41.2, Q1#20.4 (G)
Board_13-/SRC: J1#41.1, Q1#20.1 (S), Q1#20.2 (S), Q1#20.3 (S)
Board_14-/DRAIN: J1#15.3, Q1#9.5 (D)
Board_14-/GATE: J1#15.2, Q1#9.4 (G)
Board_14-/SRC: J1#15.1, Q1#9.1 (S), Q1#9.2 (S), Q1#9.3 (S)
Board_15-/DRAIN: J1#35.3, Q1#11.5 (D)
Board_15-/GATE: J1#35.2, Q1#11.4 (G)
Board_15-/SRC: J1#35.1, Q1#11.1 (S), Q1#11.2 (S), Q1#11.3 (S)
Board_16-/DRAIN: J1#5.3, Q1#10.5 (D)
Board_16-/GATE: J1#5.2, Q1#10.4 (G)
Board_16-/SRC: J1#5.1, Q1#10.1 (S), Q1#10.2 (S), Q1#10.3 (S)
Board_17-/DRAIN: J1#13.3, Q1#37.5 (D)
Board_17-/GATE: J1#13.2, Q1#37.4 (G)
Board_17-/SRC: J1#13.1, Q1#37.1 (S), Q1#37.2 (S), Q1#37.3 (S)
Board_18-/DRAIN: J1#24.3, Q1#40.5 (D)
Board_18-/GATE: J1#24.2, Q1#40.4 (G)
Board_18-/SRC: J1#24.1, Q1#40.1 (S), Q1#40.2 (S), Q1#40.3 (S)
Board_19-/DRAIN: J1#49.3, Q1#13.5 (D)
Board_19-/GATE: J1#49.2, Q1#13.4 (G)
Board_19-/SRC: J1#49.1, Q1#13.1 (S), Q1#13.2 (S), Q1#13.3 (S)
Board_20-/DRAIN: J1#26.3, Q1#22.5 (D)
Board_20-/GATE: J1#26.2, Q1#22.4 (G)
Board_20-/SRC: J1#26.1, Q1#22.1 (S), Q1#22.2 (S), Q1#22.3 (S)
Board_21-/DRAIN: J1.3, Q1#47.5 (D)
Board_21-/GATE: J1.2, Q1#47.4 (G)
Board_21-/SRC: J1.1, Q1#47.1 (S), Q1#47.2 (S), Q1#47.3 (S)
Board_22-/DRAIN: J1#23.3, Q1#3.5 (D)
Board_22-/GATE: J1#23.2, Q1#3.4 (G)
Board_22-/SRC: J1#23.1, Q1#3.1 (S), Q1#3.2 (S), Q1#3.3 (S)
Board_23-/DRAIN: J1#44.3, Q1#43.5 (D)
Board_23-/GATE: J1#44.2, Q1#43.4 (G)
Board_23-/SRC: J1#44.1, Q1#43.1 (S), Q1#43.2 (S), Q1#43.3 (S)
Board_24-/DRAIN: J1#12.3, Q1#19.5 (D)
Board_24-/GATE: J1#12.2, Q1#19.4 (G)
Board_24-/SRC: J1#12.1, Q1#19.1 (S), Q1#19.2 (S), Q1#19.3 (S)
Board_25-/DRAIN: J1#37.3, Q1#30.5 (D)
Board_25-/GATE: J1#37.2, Q1#30.4 (G)
Board_25-/SRC: J1#37.1, Q1#30.1 (S), Q1#30.2 (S), Q1#30.3 (S)
Board_26-/DRAIN: J1#47.3, Q1#46.5 (D)
Board_26-/GATE: J1#47.2, Q1#46.4 (G)
Board_26-/SRC: J1#47.1, Q1#46.1 (S), Q1#46.2 (S), Q1#46.3 (S)
Board_27-/DRAIN: J1#3.3, Q1#38.5 (D)
Board_27-/GATE: J1#3.2, Q1#38.4 (G)
Board_27-/SRC: J1#3.1, Q1#38.1 (S), Q1#38.2 (S), Q1#38.3 (S)
Board_28-/DRAIN: J1#36.3, Q1#33.5 (D)
Board_28-/GATE: J1#36.2, Q1#33.4 (G)
Board_28-/SRC: J1#36.1, Q1#33.1 (S), Q1#33.2 (S), Q1#33.3 (S)
Board_29-/DRAIN: J1#14.3, Q1#49.5 (D)
Board_29-/GATE: J1#14.2, Q1#49.4 (G)
Board_29-/SRC: J1#14.1, Q1#49.1 (S), Q1#49.2 (S), Q1#49.3 (S)
Board_30-/DRAIN: J1#38.3, Q1#34.5 (D)
Board_30-/GATE: J1#38.2, Q1#34.4 (G)
Board_30-/SRC: J1#38.1, Q1#34.1 (S), Q1#34.2 (S), Q1#34.3 (S)
Board_31-/DRAIN: J1#34.3, Q1#28.5 (D)
Board_31-/GATE: J1#34.2, Q1#28.4 (G)
Board_31-/SRC: J1#34.1, Q1#28.1 (S), Q1#28.2 (S), Q1#28.3 (S)
Board_32-/DRAIN: J1#2.3, Q1#7.5 (D)
Board_32-/GATE: J1#2.2, Q1#7.4 (G)
Board_32-/SRC: J1#2.1, Q1#7.1 (S), Q1#7.2 (S), Q1#7.3 (S)
Board_33-/DRAIN: J1#42.3, Q1#8.5 (D)
Board_33-/GATE: J1#42.2, Q1#8.4 (G)
Board_33-/SRC: J1#42.1, Q1#8.1 (S), Q1#8.2 (S), Q1#8.3 (S)
Board_34-/DRAIN: J1#19.3, Q1#25.5 (D)
Board_34-/GATE: J1#19.2, Q1#25.4 (G)
Board_34-/SRC: J1#19.1, Q1#25.1 (S), Q1#25.2 (S), Q1#25.3 (S)
Board_35-/DRAIN: J1#27.3, Q1.5 (D)
Board_35-/GATE: J1#27.2, Q1.4 (G)
Board_35-/SRC: J1#27.1, Q1.1 (S), Q1.2 (S), Q1.3 (S)
Board_36-/DRAIN: J1#25.3, Q1#18.5 (D)
Board_36-/GATE: J1#25.2, Q1#18.4 (G)
Board_36-/SRC: J1#25.1, Q1#18.1 (S), Q1#18.2 (S), Q1#18.3 (S)
Board_37-/DRAIN: J1#43.3, Q1#2.5 (D)
Board_37-/GATE: J1#43.2, Q1#2.4 (G)
Board_37-/SRC: J1#43.1, Q1#2.1 (S), Q1#2.2 (S), Q1#2.3 (S)
Board_38-/DRAIN: J1#8.3, Q1#24.5 (D)
Board_38-/GATE: J1#8.2, Q1#24.4 (G)
Board_38-/SRC: J1#8.1, Q1#24.1 (S), Q1#24.2 (S), Q1#24.3 (S)
Board_39-/DRAIN: J1#18.3, Q1#44.5 (D)
Board_39-/GATE: J1#18.2, Q1#44.4 (G)
Board_39-/SRC: J1#18.1, Q1#44.1 (S), Q1#44.2 (S), Q1#44.3 (S)
Board_40-/DRAIN: J1#6.3, Q1#16.5 (D)
Board_40-/GATE: J1#6.2, Q1#16.4 (G)
Board_40-/SRC: J1#6.1, Q1#16.1 (S), Q1#16.2 (S), Q1#16.3 (S)
Board_41-/DRAIN: J1#21.3, Q1#17.5 (D)
Board_41-/GATE: J1#21.2, Q1#17.4 (G)
Board_41-/SRC: J1#21.1, Q1#17.1 (S), Q1#17.2 (S), Q1#17.3 (S)
Board_42-/DRAIN: J1#32.3, Q1#36.5 (D)
Board_42-/GATE: J1#32.2, Q1#36.4 (G)
Board_42-/SRC: J1#32.1, Q1#36.1 (S), Q1#36.2 (S), Q1#36.3 (S)
Board_43-/DRAIN: J1#9.3, Q1#27.5 (D)
Board_43-/GATE: J1#9.2, Q1#27.4 (G)
Board_43-/SRC: J1#9.1, Q1#27.1 (S), Q1#27.2 (S), Q1#27.3 (S)
Board_44-/DRAIN: J1#39.3, Q1#42.5 (D)
Board_44-/GATE: J1#39.2, Q1#42.4 (G)
Board_44-/SRC: J1#39.1, Q1#42.1 (S), Q1#42.2 (S), Q1#42.3 (S)
Board_45-/DRAIN: J1#48.3, Q1#15.5 (D)
Board_45-/GATE: J1#48.2, Q1#15.4 (G)
Board_45-/SRC: J1#48.1, Q1#15.1 (S), Q1#15.2 (S), Q1#15.3 (S)
Board_46-/DRAIN: J1#22.3, Q1#14.5 (D)
Board_46-/GATE: J1#22.2, Q1#14.4 (G)
Board_46-/SRC: J1#22.1, Q1#14.1 (S), Q1#14.2 (S), Q1#14.3 (S)
Board_47-/DRAIN: J1#17.3, Q1#26.5 (D)
Board_47-/GATE: J1#17.2, Q1#26.4 (G)
Board_47-/SRC: J1#17.1, Q1#26.1 (S), Q1#26.2 (S), Q1#26.3 (S)
Board_48-/DRAIN: J1#16.3, Q1#4.5 (D)
Board_48-/GATE: J1#16.2, Q1#4.4 (G)
Board_48-/SRC: J1#16.1, Q1#4.1 (S), Q1#4.2 (S), Q1#4.3 (S)

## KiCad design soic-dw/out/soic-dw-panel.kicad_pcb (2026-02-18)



Board: 2 copper layers, 91.8 x 98.5 mm, 258 parts (32 on the bottom side), 248 nets.

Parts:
J1, J1#2, J1#3, J1#4, J1#5, J1#6, J1#7, J1#8: Conn_01x01; TP_HeaderPin_P2.54mm_round
J2, J2#2, J2#3, J2#4, J2#5, J2#6, J2#7, J2#8, J3, J3#2, J3#3, J3#4, J3#5, J3#6, J3#7, J3#8: Conn_01x08; PinHeader_1x08_P2.54mm_Vertical
J5, J5#2, J5#3, J5#4, J5#5, J5#6, J6, J6#2, J6#3, J6#4, J6#5, J6#6: Conn_01x10; PinHeader_1x10_P2.54mm_Vertical
KiKit_FID_B_1, KiKit_FID_B_2, KiKit_FID_B_3, KiKit_FID_B_4: Fiducial
KiKit_FID_T_1, KiKit_FID_T_2, KiKit_FID_T_3, KiKit_FID_T_4: Fiducial
KiKit_MB_1_4, KiKit_MB_1_5, KiKit_MB_1_6, KiKit_MB_1_7, KiKit_MB_1_8, KiKit_MB_1_9, KiKit_MB_1_10, KiKit_MB_2_4, KiKit_MB_2_5, KiKit_MB_2_6, KiKit_MB_2_7, KiKit_MB_2_8, KiKit_MB_2_9, KiKit_MB_2_10, KiKit_MB_3_4, KiKit_MB_3_5, KiKit_MB_3_6, KiKit_MB_3_7, KiKit_MB_3_8, KiKit_MB_3_9, KiKit_MB_3_10, KiKit_MB_4_4, KiKit_MB_4_5, KiKit_MB_4_6, KiKit_MB_4_7, KiKit_MB_4_8, KiKit_MB_4_9, KiKit_MB_4_10, KiKit_MB_5_4, KiKit_MB_5_5, KiKit_MB_5_6, KiKit_MB_5_7, KiKit_MB_5_8, KiKit_MB_5_9, KiKit_MB_5_10, KiKit_MB_6_4, KiKit_MB_6_5, KiKit_MB_6_6, KiKit_MB_6_7, KiKit_MB_6_8, KiKit_MB_6_9, KiKit_MB_6_10, KiKit_MB_7_4, KiKit_MB_7_5, KiKit_MB_7_6, KiKit_MB_7_7, KiKit_MB_7_8, KiKit_MB_7_9, KiKit_MB_7_10, KiKit_MB_8_4, KiKit_MB_8_5, KiKit_MB_8_6, KiKit_MB_8_7, KiKit_MB_8_8, KiKit_MB_8_9, KiKit_MB_8_10, KiKit_MB_9_4, KiKit_MB_9_5, KiKit_MB_9_6, KiKit_MB_9_7, KiKit_MB_9_8, KiKit_MB_9_9, KiKit_MB_9_10, KiKit_MB_10_4, KiKit_MB_10_5, KiKit_MB_10_6, KiKit_MB_10_7, KiKit_MB_10_8, KiKit_MB_10_9, KiKit_MB_10_10, KiKit_MB_11_4, KiKit_MB_11_5, KiKit_MB_11_6, KiKit_MB_11_7, KiKit_MB_11_8, KiKit_MB_11_9, KiKit_MB_11_10, KiKit_MB_12_4, KiKit_MB_12_5, KiKit_MB_12_6, KiKit_MB_12_7, KiKit_MB_12_8, KiKit_MB_12_9, KiKit_MB_12_10, KiKit_MB_13_4, KiKit_MB_13_5, KiKit_MB_13_6, KiKit_MB_13_7, KiKit_MB_13_8, KiKit_MB_13_9, KiKit_MB_13_10, KiKit_MB_14_4, KiKit_MB_14_5, KiKit_MB_14_6, KiKit_MB_14_7, KiKit_MB_14_8, KiKit_MB_14_9, KiKit_MB_14_10, KiKit_MB_15_4, KiKit_MB_15_5, KiKit_MB_15_6, KiKit_MB_15_7, KiKit_MB_15_8, KiKit_MB_15_9, KiKit_MB_15_10, KiKit_MB_16_4, KiKit_MB_16_5, KiKit_MB_16_6, KiKit_MB_16_7, KiKit_MB_16_8, KiKit_MB_16_9, KiKit_MB_16_10, KiKit_MB_17_4, KiKit_MB_17_5, KiKit_MB_17_6, KiKit_MB_17_7, KiKit_MB_17_8, KiKit_MB_17_9, KiKit_MB_17_10, KiKit_MB_18_4, KiKit_MB_18_5, KiKit_MB_18_6, KiKit_MB_18_7, KiKit_MB_18_8, KiKit_MB_18_9, KiKit_MB_18_10, KiKit_MB_19_4, KiKit_MB_19_5, KiKit_MB_19_6, KiKit_MB_19_7, KiKit_MB_19_8, KiKit_MB_19_9, KiKit_MB_19_10, KiKit_MB_20_4, KiKit_MB_20_5, KiKit_MB_20_6, KiKit_MB_20_7, KiKit_MB_20_8, KiKit_MB_20_9, KiKit_MB_20_10, KiKit_MB_21_4, KiKit_MB_21_5, KiKit_MB_21_6, KiKit_MB_21_7, KiKit_MB_21_8, KiKit_MB_21_9, KiKit_MB_21_10, KiKit_MB_22_4, KiKit_MB_22_5, KiKit_MB_22_6, KiKit_MB_22_7, KiKit_MB_22_8, KiKit_MB_22_9, KiKit_MB_22_10, KiKit_MB_23_4, KiKit_MB_23_5, KiKit_MB_23_6, KiKit_MB_23_7, KiKit_MB_23_8, KiKit_MB_23_9, KiKit_MB_23_10, KiKit_MB_24_4, KiKit_MB_24_5, KiKit_MB_24_6, KiKit_MB_24_7, KiKit_MB_24_8, KiKit_MB_24_9, KiKit_MB_24_10, KiKit_MB_25_4, KiKit_MB_25_5, KiKit_MB_25_6, KiKit_MB_25_7, KiKit_MB_25_8, KiKit_MB_25_9, KiKit_MB_25_10, KiKit_MB_26_4, KiKit_MB_26_5, KiKit_MB_26_6, KiKit_MB_26_7, KiKit_MB_26_8, KiKit_MB_26_9, KiKit_MB_26_10, KiKit_MB_27_4, KiKit_MB_27_5, KiKit_MB_27_6, KiKit_MB_27_7, KiKit_MB_27_8, KiKit_MB_27_9, KiKit_MB_27_10, KiKit_MB_28_4, KiKit_MB_28_5, KiKit_MB_28_6, KiKit_MB_28_7, KiKit_MB_28_8, KiKit_MB_28_9, KiKit_MB_28_10: NPTH
KiKit_TO_1, KiKit_TO_2, KiKit_TO_3, KiKit_TO_4: NPTH
U1, U1#2, U1#3, U1#4, U1#5, U1#6, U1#7, U1#8: SOIC-DW-16; TI_SOIC_DW0016A_MinSilk
U2, U2#2, U2#3, U2#4, U2#5, U2#6: SOIC-DW-20; TI_SOIC_DW0020A

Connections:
Board_0-Net-(J2-Pin_1): J2#8.1, U1.16
Board_0-Net-(J2-Pin_2): J2#8.2, U1.15
Board_0-Net-(J2-Pin_3): J2#8.3, U1.14
Board_0-Net-(J2-Pin_4): J2#8.4, U1.13
Board_0-Net-(J2-Pin_5): J2#8.5, U1.12
Board_0-Net-(J2-Pin_6): J2#8.6, U1.11
Board_0-Net-(J2-Pin_7): J2#8.7, U1.10
Board_0-Net-(J2-Pin_8): J2#8.8, U1.9
Board_0-Net-(J3-Pin_1): J3#5.1, U1.1
Board_0-Net-(J3-Pin_2): J3#5.2, U1.2
Board_0-Net-(J3-Pin_3): J3#5.3, U1.3
Board_0-Net-(J3-Pin_4): J3#5.4, U1.4
Board_0-Net-(J3-Pin_5): J3#5.5, U1.5
Board_0-Net-(J3-Pin_6): J3#5.6, U1.6
Board_0-Net-(J3-Pin_7): J3#5.7, U1.7
Board_0-Net-(J3-Pin_8): J3#5.8, U1.8
Board_1-Net-(J2-Pin_1): J2#3.1, U1#5.16
Board_1-Net-(J2-Pin_2): J2#3.2, U1#5.15
Board_1-Net-(J2-Pin_3): J2#3.3, U1#5.14
Board_1-Net-(J2-Pin_4): J2#3.4, U1#5.13
Board_1-Net-(J2-Pin_5): J2#3.5, U1#5.12
Board_1-Net-(J2-Pin_6): J2#3.6, U1#5.11
Board_1-Net-(J2-Pin_7): J2#3.7, U1#5.10
Board_1-Net-(J2-Pin_8): J2#3.8, U1#5.9
Board_1-Net-(J3-Pin_1): J3#7.1, U1#5.1
Board_1-Net-(J3-Pin_2): J3#7.2, U1#5.2
Board_1-Net-(J3-Pin_3): J3#7.3, U1#5.3
Board_1-Net-(J3-Pin_4): J3#7.4, U1#5.4
Board_1-Net-(J3-Pin_5): J3#7.5, U1#5.5
Board_1-Net-(J3-Pin_6): J3#7.6, U1#5.6
Board_1-Net-(J3-Pin_7): J3#7.7, U1#5.7
Board_1-Net-(J3-Pin_8): J3#7.8, U1#5.8
Board_2-Net-(J2-Pin_1): J2#2.1, U1#3.16
Board_2-Net-(J2-Pin_2): J2#2.2, U1#3.15
Board_2-Net-(J2-Pin_3): J2#2.3, U1#3.14
Board_2-Net-(J2-Pin_4): J2#2.4, U1#3.13
Board_2-Net-(J2-Pin_5): J2#2.5, U1#3.12
Board_2-Net-(J2-Pin_6): J2#2.6, U1#3.11
Board_2-Net-(J2-Pin_7): J2#2.7, U1#3.10
Board_2-Net-(J2-Pin_8): J2#2.8, U1#3.9
Board_2-Net-(J3-Pin_1): J3#8.1, U1#3.1
Board_2-Net-(J3-Pin_2): J3#8.2, U1#3.2
Board_2-Net-(J3-Pin_3): J3#8.3, U1#3.3
Board_2-Net-(J3-Pin_4): J3#8.4, U1#3.4
Board_2-Net-(J3-Pin_5): J3#8.5, U1#3.5
Board_2-Net-(J3-Pin_6): J3#8.6, U1#3.6
Board_2-Net-(J3-Pin_7): J3#8.7, U1#3.7
Board_2-Net-(J3-Pin_8): J3#8.8, U1#3.8
Board_3-Net-(J2-Pin_1): J2.1, U1#4.16
Board_3-Net-(J2-Pin_2): J2.2, U1#4.15
Board_3-Net-(J2-Pin_3): J2.3, U1#4.14
Board_3-Net-(J2-Pin_4): J2.4, U1#4.13
Board_3-Net-(J2-Pin_5): J2.5, U1#4.12
Board_3-Net-(J2-Pin_6): J2.6, U1#4.11
Board_3-Net-(J2-Pin_7): J2.7, U1#4.10
Board_3-Net-(J2-Pin_8): J2.8, U1#4.9
Board_3-Net-(J3-Pin_1): J3#6.1, U1#4.1
Board_3-Net-(J3-Pin_2): J3#6.2, U1#4.2
Board_3-Net-(J3-Pin_3): J3#6.3, U1#4.3
Board_3-Net-(J3-Pin_4): J3#6.4, U1#4.4
Board_3-Net-(J3-Pin_5): J3#6.5, U1#4.5
Board_3-Net-(J3-Pin_6): J3#6.6, U1#4.6
Board_3-Net-(J3-Pin_7): J3#6.7, U1#4.7
Board_3-Net-(J3-Pin_8): J3#6.8, U1#4.8
Board_4-Net-(J2-Pin_1): J2#7.1, U1#7.16
Board_4-Net-(J2-Pin_2): J2#7.2, U1#7.15
Board_4-Net-(J2-Pin_3): J2#7.3, U1#7.14
Board_4-Net-(J2-Pin_4): J2#7.4, U1#7.13
Board_4-Net-(J2-Pin_5): J2#7.5, U1#7.12
Board_4-Net-(J2-Pin_6): J2#7.6, U1#7.11
Board_4-Net-(J2-Pin_7): J2#7.7, U1#7.10
Board_4-Net-(J2-Pin_8): J2#7.8, U1#7.9
Board_4-Net-(J3-Pin_1): J3#2.1, U1#7.1
Board_4-Net-(J3-Pin_2): J3#2.2, U1#7.2
Board_4-Net-(J3-Pin_3): J3#2.3, U1#7.3
Board_4-Net-(J3-Pin_4): J3#2.4, U1#7.4
Board_4-Net-(J3-Pin_5): J3#2.5, U1#7.5
Board_4-Net-(J3-Pin_6): J3#2.6, U1#7.6
Board_4-Net-(J3-Pin_7): J3#2.7, U1#7.7
Board_4-Net-(J3-Pin_8): J3#2.8, U1#7.8
Board_5-Net-(J2-Pin_1): J2#6.1, U1#6.16
Board_5-Net-(J2-Pin_2): J2#6.2, U1#6.15
Board_5-Net-(J2-Pin_3): J2#6.3, U1#6.14
Board_5-Net-(J2-Pin_4): J2#6.4, U1#6.13
Board_5-Net-(J2-Pin_5): J2#6.5, U1#6.12
Board_5-Net-(J2-Pin_6): J2#6.6, U1#6.11
Board_5-Net-(J2-Pin_7): J2#6.7, U1#6.10
Board_5-Net-(J2-Pin_8): J2#6.8, U1#6.9
Board_5-Net-(J3-Pin_1): J3#4.1, U1#6.1
Board_5-Net-(J3-Pin_2): J3#4.2, U1#6.2
Board_5-Net-(J3-Pin_3): J3#4.3, U1#6.3
Board_5-Net-(J3-Pin_4): J3#4.4, U1#6.4
Board_5-Net-(J3-Pin_5): J3#4.5, U1#6.5
Board_5-Net-(J3-Pin_6): J3#4.6, U1#6.6
Board_5-Net-(J3-Pin_7): J3#4.7, U1#6.7
Board_5-Net-(J3-Pin_8): J3#4.8, U1#6.8
Board_6-Net-(J2-Pin_1): J2#4.1, U1#2.16
Board_6-Net-(J2-Pin_2): J2#4.2, U1#2.15
Board_6-Net-(J2-Pin_3): J2#4.3, U1#2.14
Board_6-Net-(J2-Pin_4): J2#4.4, U1#2.13
Board_6-Net-(J2-Pin_5): J2#4.5, U1#2.12
Board_6-Net-(J2-Pin_6): J2#4.6, U1#2.11
Board_6-Net-(J2-Pin_7): J2#4.7, U1#2.10
Board_6-Net-(J2-Pin_8): J2#4.8, U1#2.9
Board_6-Net-(J3-Pin_1): J3#3.1, U1#2.1
Board_6-Net-(J3-Pin_2): J3#3.2, U1#2.2
Board_6-Net-(J3-Pin_3): J3#3.3, U1#2.3
Board_6-Net-(J3-Pin_4): J3#3.4, U1#2.4
Board_6-Net-(J3-Pin_5): J3#3.5, U1#2.5
Board_6-Net-(J3-Pin_6): J3#3.6, U1#2.6
Board_6-Net-(J3-Pin_7): J3#3.7, U1#2.7
Board_6-Net-(J3-Pin_8): J3#3.8, U1#2.8
Board_7-Net-(J2-Pin_1): J2#5.1, U1#8.16
Board_7-Net-(J2-Pin_2): J2#5.2, U1#8.15
Board_7-Net-(J2-Pin_3): J2#5.3, U1#8.14
Board_7-Net-(J2-Pin_4): J2#5.4, U1#8.13
Board_7-Net-(J2-Pin_5): J2#5.5, U1#8.12
Board_7-Net-(J2-Pin_6): J2#5.6, U1#8.11
Board_7-Net-(J2-Pin_7): J2#5.7, U1#8.10
Board_7-Net-(J2-Pin_8): J2#5.8, U1#8.9
Board_7-Net-(J3-Pin_1): J3.1, U1#8.1
Board_7-Net-(J3-Pin_2): J3.2, U1#8.2
Board_7-Net-(J3-Pin_3): J3.3, U1#8.3
Board_7-Net-(J3-Pin_4): J3.4, U1#8.4
Board_7-Net-(J3-Pin_5): J3.5, U1#8.5
Board_7-Net-(J3-Pin_6): J3.6, U1#8.6
Board_7-Net-(J3-Pin_7): J3.7, U1#8.7
Board_7-Net-(J3-Pin_8): J3.8, U1#8.8
Board_8-Net-(J5-Pin_1): J5.1, U2#4.20
Board_8-Net-(J5-Pin_2): J5.2, U2#4.19
Board_8-Net-(J5-Pin_3): J5.3, U2#4.18
Board_8-Net-(J5-Pin_4): J5.4, U2#4.17
Board_8-Net-(J5-Pin_5): J5.5, U2#4.16
Board_8-Net-(J5-Pin_6): J5.6, U2#4.15
Board_8-Net-(J5-Pin_7): J5.7, U2#4.14
Board_8-Net-(J5-Pin_8): J5.8, U2#4.13
Board_8-Net-(J5-Pin_9): J5.9, U2#4.12
Board_8-Net-(J5-Pin_10): J5.10, U2#4.11
Board_8-Net-(J6-Pin_1): J6.1, U2#4.1
Board_8-Net-(J6-Pin_2): J6.2, U2#4.2
Board_8-Net-(J6-Pin_3): J6.3, U2#4.3
Board_8-Net-(J6-Pin_4): J6.4, U2#4.4
Board_8-Net-(J6-Pin_5): J6.5, U2#4.5
Board_8-Net-(J6-Pin_6): J6.6, U2#4.6
Board_8-Net-(J6-Pin_7): J6.7, U2#4.7
Board_8-Net-(J6-Pin_8): J6.8, U2#4.8
Board_8-Net-(J6-Pin_9): J6.9, U2#4.9
Board_8-Net-(J6-Pin_10): J6.10, U2#4.10
Board_9-Net-(J5-Pin_1): J5#5.1, U2#2.20
Board_9-Net-(J5-Pin_2): J5#5.2, U2#2.19
Board_9-Net-(J5-Pin_3): J5#5.3, U2#2.18
Board_9-Net-(J5-Pin_4): J5#5.4, U2#2.17
Board_9-Net-(J5-Pin_5): J5#5.5, U2#2.16
Board_9-Net-(J5-Pin_6): J5#5.6, U2#2.15
Board_9-Net-(J5-Pin_7): J5#5.7, U2#2.14
Board_9-Net-(J5-Pin_8): J5#5.8, U2#2.13
Board_9-Net-(J5-Pin_9): J5#5.9, U2#2.12
Board_9-Net-(J5-Pin_10): J5#5.10, U2#2.11
Board_9-Net-(J6-Pin_1): J6#2.1, U2#2.1
Board_9-Net-(J6-Pin_2): J6#2.2, U2#2.2
Board_9-Net-(J6-Pin_3): J6#2.3, U2#2.3
Board_9-Net-(J6-Pin_4): J6#2.4, U2#2.4
Board_9-Net-(J6-Pin_5): J6#2.5, U2#2.5
Board_9-Net-(J6-Pin_6): J6#2.6, U2#2.6
Board_9-Net-(J6-Pin_7): J6#2.7, U2#2.7
Board_9-Net-(J6-Pin_8): J6#2.8, U2#2.8
Board_9-Net-(J6-Pin_9): J6#2.9, U2#2.9
Board_9-Net-(J6-Pin_10): J6#2.10, U2#2.10
Board_10-Net-(J5-Pin_1): J5#2.1, U2#6.20
Board_10-Net-(J5-Pin_2): J5#2.2, U2#6.19
Board_10-Net-(J5-Pin_3): J5#2.3, U2#6.18
Board_10-Net-(J5-Pin_4): J5#2.4, U2#6.17
Board_10-Net-(J5-Pin_5): J5#2.5, U2#6.16
Board_10-Net-(J5-Pin_6): J5#2.6, U2#6.15
Board_10-Net-(J5-Pin_7): J5#2.7, U2#6.14
Board_10-Net-(J5-Pin_8): J5#2.8, U2#6.13
Board_10-Net-(J5-Pin_9): J5#2.9, U2#6.12
Board_10-Net-(J5-Pin_10): J5#2.10, U2#6.11
Board_10-Net-(J6-Pin_1): J6#5.1, U2#6.1
Board_10-Net-(J6-Pin_2): J6#5.2, U2#6.2
Board_10-Net-(J6-Pin_3): J6#5.3, U2#6.3
Board_10-Net-(J6-Pin_4): J6#5.4, U2#6.4
Board_10-Net-(J6-Pin_5): J6#5.5, U2#6.5
Board_10-Net-(J6-Pin_6): J6#5.6, U2#6.6
Board_10-Net-(J6-Pin_7): J6#5.7, U2#6.7
Board_10-Net-(J6-Pin_8): J6#5.8, U2#6.8
Board_10-Net-(J6-Pin_9): J6#5.9, U2#6.9
Board_10-Net-(J6-Pin_10): J6#5.10, U2#6.10
Board_11-Net-(J5-Pin_1): J5#4.1, U2.20
Board_11-Net-(J5-Pin_2): J5#4.2, U2.19
Board_11-Net-(J5-Pin_3): J5#4.3, U2.18
Board_11-Net-(J5-Pin_4): J5#4.4, U2.17
Board_11-Net-(J5-Pin_5): J5#4.5, U2.16
Board_11-Net-(J5-Pin_6): J5#4.6, U2.15
Board_11-Net-(J5-Pin_7): J5#4.7, U2.14
Board_11-Net-(J5-Pin_8): J5#4.8, U2.13
Board_11-Net-(J5-Pin_9): J5#4.9, U2.12
Board_11-Net-(J5-Pin_10): J5#4.10, U2.11
Board_11-Net-(J6-Pin_1): J6#4.1, U2.1
Board_11-Net-(J6-Pin_2): J6#4.2, U2.2
Board_11-Net-(J6-Pin_3): J6#4.3, U2.3
Board_11-Net-(J6-Pin_4): J6#4.4, U2.4
Board_11-Net-(J6-Pin_5): J6#4.5, U2.5
Board_11-Net-(J6-Pin_6): J6#4.6, U2.6
Board_11-Net-(J6-Pin_7): J6#4.7, U2.7
Board_11-Net-(J6-Pin_8): J6#4.8, U2.8
Board_11-Net-(J6-Pin_9): J6#4.9, U2.9
Board_11-Net-(J6-Pin_10): J6#4.10, U2.10
Board_12-Net-(J5-Pin_1): J5#3.1, U2#5.20
Board_12-Net-(J5-Pin_2): J5#3.2, U2#5.19
Board_12-Net-(J5-Pin_3): J5#3.3, U2#5.18
Board_12-Net-(J5-Pin_4): J5#3.4, U2#5.17
Board_12-Net-(J5-Pin_5): J5#3.5, U2#5.16
Board_12-Net-(J5-Pin_6): J5#3.6, U2#5.15
Board_12-Net-(J5-Pin_7): J5#3.7, U2#5.14
Board_12-Net-(J5-Pin_8): J5#3.8, U2#5.13
Board_12-Net-(J5-Pin_9): J5#3.9, U2#5.12
Board_12-Net-(J5-Pin_10): J5#3.10, U2#5.11
Board_12-Net-(J6-Pin_1): J6#3.1, U2#5.1
Board_12-Net-(J6-Pin_2): J6#3.2, U2#5.2
Board_12-Net-(J6-Pin_3): J6#3.3, U2#5.3
Board_12-Net-(J6-Pin_4): J6#3.4, U2#5.4
Board_12-Net-(J6-Pin_5): J6#3.5, U2#5.5
Board_12-Net-(J6-Pin_6): J6#3.6, U2#5.6
Board_12-Net-(J6-Pin_7): J6#3.7, U2#5.7
Board_12-Net-(J6-Pin_8): J6#3.8, U2#5.8
Board_12-Net-(J6-Pin_9): J6#3.9, U2#5.9
Board_12-Net-(J6-Pin_10): J6#3.10, U2#5.10
Board_13-Net-(J5-Pin_1): J5#6.1, U2#3.20
Board_13-Net-(J5-Pin_2): J5#6.2, U2#3.19
Board_13-Net-(J5-Pin_3): J5#6.3, U2#3.18
Board_13-Net-(J5-Pin_4): J5#6.4, U2#3.17
Board_13-Net-(J5-Pin_5): J5#6.5, U2#3.16
Board_13-Net-(J5-Pin_6): J5#6.6, U2#3.15
Board_13-Net-(J5-Pin_7): J5#6.7, U2#3.14
Board_13-Net-(J5-Pin_8): J5#6.8, U2#3.13
Board_13-Net-(J5-Pin_9): J5#6.9, U2#3.12
Board_13-Net-(J5-Pin_10): J5#6.10, U2#3.11
Board_13-Net-(J6-Pin_1): J6#6.1, U2#3.1
Board_13-Net-(J6-Pin_2): J6#6.2, U2#3.2
Board_13-Net-(J6-Pin_3): J6#6.3, U2#3.3
Board_13-Net-(J6-Pin_4): J6#6.4, U2#3.4
Board_13-Net-(J6-Pin_5): J6#6.5, U2#3.5
Board_13-Net-(J6-Pin_6): J6#6.6, U2#3.6
Board_13-Net-(J6-Pin_7): J6#6.7, U2#3.7
Board_13-Net-(J6-Pin_8): J6#6.8, U2#3.8
Board_13-Net-(J6-Pin_9): J6#6.9, U2#3.9
Board_13-Net-(J6-Pin_10): J6#6.10, U2#3.10

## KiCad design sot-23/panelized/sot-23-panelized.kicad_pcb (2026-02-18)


Board: 2 copper layers, 94.2 x 87.9 mm, 780 parts (0 on the bottom side), 360 nets.

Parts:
J1, J1#2, J1#3, J1#4, J1#5, J1#6, J1#7, J1#8, J1#9, J1#10, J1#11, J1#12, J1#13, J1#14, J1#15, J1#16, J1#17, J1#18, J1#19, J1#20, J1#21, J1#22, J1#23, J1#24, J1#25, J1#26, J1#27, J1#28, J1#29, J1#30, J1#31, J1#32, J1#33, J1#34, J1#35, J1#36, J1#37, J1#38, J1#39, J1#40, J1#41, J1#42, J1#43, J1#44, J1#45, J1#46, J1#47, J1#48, J1#49, J1#50, J1#51, J1#52, J1#53, J1#54, J1#55, J1#56, J1#57, J1#58, J1#59, J1#60, J2, J2#2, J2#3, J2#4, J2#5, J2#6, J2#7, J2#8, J2#9, J2#10, J2#11, J2#12, J2#13, J2#14, J2#15, J2#16, J2#17, J2#18, J2#19, J2#20, J2#21, J2#22, J2#23, J2#24, J2#25, J2#26, J2#27, J2#28, J2#29, J2#30, J2#31, J2#32, J2#33, J2#34, J2#35, J2#36, J2#37, J2#38, J2#39, J2#40, J2#41, J2#42, J2#43, J2#44, J2#45, J2#46, J2#47, J2#48, J2#49, J2#50, J2#51, J2#52, J2#53, J2#54, J2#55, J2#56, J2#57, J2#58, J2#59, J2#60: Conn_01x03; PinHeader_1x03_P2.54mm_Vertical
KiKit_MB_1_2, KiKit_MB_1_3, KiKit_MB_1_4, KiKit_MB_1_5, KiKit_MB_1_6, KiKit_MB_2_2, KiKit_MB_2_3, KiKit_MB_2_4, KiKit_MB_2_5, KiKit_MB_2_6, KiKit_MB_3_2, KiKit_MB_3_3, KiKit_MB_3_4, KiKit_MB_3_5, KiKit_MB_3_6, KiKit_MB_4_2, KiKit_MB_4_3, KiKit_MB_4_4, KiKit_MB_4_5, KiKit_MB_4_6, KiKit_MB_5_2, KiKit_MB_5_3, KiKit_MB_5_4, KiKit_MB_5_5, KiKit_MB_5_6, KiKit_MB_6_2, KiKit_MB_6_3, KiKit_MB_6_4, KiKit_MB_6_5, KiKit_MB_6_6, KiKit_MB_7_2, KiKit_MB_7_3, KiKit_MB_7_4, KiKit_MB_7_5, KiKit_MB_7_6, KiKit_MB_8_2, KiKit_MB_8_3, KiKit_MB_8_4, KiKit_MB_8_5, KiKit_MB_8_6, KiKit_MB_9_2, KiKit_MB_9_3, KiKit_MB_9_4, KiKit_MB_9_5, KiKit_MB_9_6, KiKit_MB_10_2, KiKit_MB_10_3, KiKit_MB_10_4, KiKit_MB_10_5, KiKit_MB_10_6, KiKit_MB_11_2, KiKit_MB_11_3, KiKit_MB_11_4, KiKit_MB_11_5, KiKit_MB_11_6, KiKit_MB_12_2, KiKit_MB_12_3, KiKit_MB_12_4, KiKit_MB_12_5, KiKit_MB_12_6, KiKit_MB_13_2, KiKit_MB_13_3, KiKit_MB_13_4, KiKit_MB_13_5, KiKit_MB_13_6, KiKit_MB_14_2, KiKit_MB_14_3, KiKit_MB_14_4, KiKit_MB_14_5, KiKit_MB_14_6, KiKit_MB_15_2, KiKit_MB_15_3, KiKit_MB_15_4, KiKit_MB_15_5, KiKit_MB_15_6, KiKit_MB_16_2, KiKit_MB_16_3, KiKit_MB_16_4, KiKit_MB_16_5, KiKit_MB_16_6, KiKit_MB_17_2, KiKit_MB_17_3, KiKit_MB_17_4, KiKit_MB_17_5, KiKit_MB_17_6, KiKit_MB_18_2, KiKit_MB_18_3, KiKit_MB_18_4, KiKit_MB_18_5, KiKit_MB_18_6, KiKit_MB_19_2, KiKit_MB_19_3, KiKit_MB_19_4, KiKit_MB_19_5, KiKit_MB_19_6, KiKit_MB_20_2, KiKit_MB_20_3, KiKit_MB_20_4, KiKit_MB_20_5, KiKit_MB_20_6, KiKit_MB_21_2, KiKit_MB_21_3, KiKit_MB_21_4, KiKit_MB_21_5, KiKit_MB_21_6, KiKit_MB_22_2, KiKit_MB_22_3, KiKit_MB_22_4, KiKit_MB_22_5, KiKit_MB_22_6, KiKit_MB_23_2, KiKit_MB_23_3, KiKit_MB_23_4, KiKit_MB_23_5, KiKit_MB_23_6, KiKit_MB_24_2, KiKit_MB_24_3, KiKit_MB_24_4, KiKit_MB_24_5, KiKit_MB_24_6, KiKit_MB_25_2, KiKit_MB_25_3, KiKit_MB_25_4, KiKit_MB_25_5, KiKit_MB_25_6, KiKit_MB_26_2, KiKit_MB_26_3, KiKit_MB_26_4, KiKit_MB_26_5, KiKit_MB_26_6, KiKit_MB_27_2, KiKit_MB_27_3, KiKit_MB_27_4, KiKit_MB_27_5, KiKit_MB_27_6, KiKit_MB_28_2, KiKit_MB_28_3, KiKit_MB_28_4, KiKit_MB_28_5, KiKit_MB_28_6, KiKit_MB_29_2, KiKit_MB_29_3, KiKit_MB_29_4, KiKit_MB_29_5, KiKit_MB_29_6, KiKit_MB_30_2, KiKit_MB_30_3, KiKit_MB_30_4, KiKit_MB_30_5, KiKit_MB_30_6, KiKit_MB_31_2, KiKit_MB_31_3, KiKit_MB_31_4, KiKit_MB_31_5, KiKit_MB_31_6, KiKit_MB_32_2, KiKit_MB_32_3, KiKit_MB_32_4, KiKit_MB_32_5, KiKit_MB_32_6, KiKit_MB_33_2, KiKit_MB_33_3, KiKit_MB_33_4, KiKit_MB_33_5, KiKit_MB_33_6, KiKit_MB_34_2, KiKit_MB_34_3, KiKit_MB_34_4, KiKit_MB_34_5, KiKit_MB_34_6, KiKit_MB_35_2, KiKit_MB_35_3, KiKit_MB_35_4, KiKit_MB_35_5, KiKit_MB_35_6, KiKit_MB_36_2, KiKit_MB_36_3, KiKit_MB_36_4, KiKit_MB_36_5, KiKit_MB_36_6, KiKit_MB_37_2, KiKit_MB_37_3, KiKit_MB_37_4, KiKit_MB_37_5, KiKit_MB_37_6, KiKit_MB_38_2, KiKit_MB_38_3, KiKit_MB_38_4, KiKit_MB_38_5, KiKit_MB_38_6, KiKit_MB_39_2, KiKit_MB_39_3, KiKit_MB_39_4, KiKit_MB_39_5, KiKit_MB_39_6, KiKit_MB_40_2, KiKit_MB_40_3, KiKit_MB_40_4, KiKit_MB_40_5, KiKit_MB_40_6, KiKit_MB_41_2, KiKit_MB_41_3, KiKit_MB_41_4, KiKit_MB_41_5, KiKit_MB_41_6, KiKit_MB_42_2, KiKit_MB_42_3, KiKit_MB_42_4, KiKit_MB_42_5, KiKit_MB_42_6, KiKit_MB_43_2, KiKit_MB_43_3, KiKit_MB_43_4, KiKit_MB_43_5, KiKit_MB_43_6, KiKit_MB_44_2, KiKit_MB_44_3, KiKit_MB_44_4, KiKit_MB_44_5, KiKit_MB_44_6, KiKit_MB_45_2, KiKit_MB_45_3, KiKit_MB_45_4, KiKit_MB_45_5, KiKit_MB_45_6, KiKit_MB_46_2, KiKit_MB_46_3, KiKit_MB_46_4, KiKit_MB_46_5, KiKit_MB_46_6, KiKit_MB_47_2, KiKit_MB_47_3, KiKit_MB_47_4, KiKit_MB_47_5, KiKit_MB_47_6, KiKit_MB_48_2, KiKit_MB_48_3, KiKit_MB_48_4, KiKit_MB_48_5, KiKit_MB_48_6, KiKit_MB_49_2, KiKit_MB_49_3, KiKit_MB_49_4, KiKit_MB_49_5, KiKit_MB_49_6, KiKit_MB_50_2, KiKit_MB_50_3, KiKit_MB_50_4, KiKit_MB_50_5, KiKit_MB_50_6, KiKit_MB_51_2, KiKit_MB_51_3, KiKit_MB_51_4, KiKit_MB_51_5, KiKit_MB_51_6, KiKit_MB_52_2, KiKit_MB_52_3, KiKit_MB_52_4, KiKit_MB_52_5, KiKit_MB_52_6, KiKit_MB_53_2, KiKit_MB_53_3, KiKit_MB_53_4, KiKit_MB_53_5, KiKit_MB_53_6, KiKit_MB_54_2, KiKit_MB_54_3, KiKit_MB_54_4, KiKit_MB_54_5, KiKit_MB_54_6, KiKit_MB_55_2, KiKit_MB_55_3, KiKit_MB_55_4, KiKit_MB_55_5, KiKit_MB_55_6, KiKit_MB_56_2, KiKit_MB_56_3, KiKit_MB_56_4, KiKit_MB_56_5, KiKit_MB_56_6, KiKit_MB_57_2, KiKit_MB_57_3, KiKit_MB_57_4, KiKit_MB_57_5, KiKit_MB_57_6, KiKit_MB_58_2, KiKit_MB_58_3, KiKit_MB_58_4, KiKit_MB_58_5, KiKit_MB_58_6, KiKit_MB_59_2, KiKit_MB_59_3, KiKit_MB_59_4, KiKit_MB_59_5, KiKit_MB_59_6, KiKit_MB_60_2, KiKit_MB_60_3, KiKit_MB_60_4, KiKit_MB_60_5, KiKit_MB_60_6, KiKit_MB_61_2, KiKit_MB_61_3, KiKit_MB_61_4, KiKit_MB_61_5, KiKit_MB_61_6, KiKit_MB_62_2, KiKit_MB_62_3, KiKit_MB_62_4, KiKit_MB_62_5, KiKit_MB_62_6, KiKit_MB_63_2, KiKit_MB_63_3, KiKit_MB_63_4, KiKit_MB_63_5, KiKit_MB_63_6, KiKit_MB_64_2, KiKit_MB_64_3, KiKit_MB_64_4, KiKit_MB_64_5, KiKit_MB_64_6, KiKit_MB_65_2, KiKit_MB_65_3, KiKit_MB_65_4, KiKit_MB_65_5, KiKit_MB_65_6, KiKit_MB_66_2, KiKit_MB_66_3, KiKit_MB_66_4, KiKit_MB_66_5, KiKit_MB_66_6, KiKit_MB_67_2, KiKit_MB_67_3, KiKit_MB_67_4, KiKit_MB_67_5, KiKit_MB_67_6, KiKit_MB_68_2, KiKit_MB_68_3, KiKit_MB_68_4, KiKit_MB_68_5, KiKit_MB_68_6, KiKit_MB_69_2, KiKit_MB_69_3, KiKit_MB_69_4, KiKit_MB_69_5, KiKit_MB_69_6, KiKit_MB_70_2, KiKit_MB_70_3, KiKit_MB_70_4, KiKit_MB_70_5, KiKit_MB_70_6, KiKit_MB_71_2, KiKit_MB_71_3, KiKit_MB_71_4, KiKit_MB_71_5, KiKit_MB_71_6, KiKit_MB_72_2, KiKit_MB_72_3, KiKit_MB_72_4, KiKit_MB_72_5, KiKit_MB_72_6, KiKit_MB_73_2, KiKit_MB_73_3, KiKit_MB_73_4, KiKit_MB_73_5, KiKit_MB_73_6, KiKit_MB_74_2, KiKit_MB_74_3, KiKit_MB_74_4, KiKit_MB_74_5, KiKit_MB_74_6, KiKit_MB_75_2, KiKit_MB_75_3, KiKit_MB_75_4, KiKit_MB_75_5, KiKit_MB_75_6, KiKit_MB_76_2, KiKit_MB_76_3, KiKit_MB_76_4, KiKit_MB_76_5, KiKit_MB_76_6, KiKit_MB_77_2, KiKit_MB_77_3, KiKit_MB_77_4, KiKit_MB_77_5, KiKit_MB_77_6, KiKit_MB_78_2, KiKit_MB_78_3, KiKit_MB_78_4, KiKit_MB_78_5, KiKit_MB_78_6, KiKit_MB_79_2, KiKit_MB_79_3, KiKit_MB_79_4, KiKit_MB_79_5, KiKit_MB_79_6, KiKit_MB_80_2, KiKit_MB_80_3, KiKit_MB_80_4, KiKit_MB_80_5, KiKit_MB_80_6, KiKit_MB_81_2, KiKit_MB_81_3, KiKit_MB_81_4, KiKit_MB_81_5, KiKit_MB_81_6, KiKit_MB_82_2, KiKit_MB_82_3, KiKit_MB_82_4, KiKit_MB_82_5, KiKit_MB_82_6, KiKit_MB_83_2, KiKit_MB_83_3, KiKit_MB_83_4, KiKit_MB_83_5, KiKit_MB_83_6, KiKit_MB_84_2, KiKit_MB_84_3, KiKit_MB_84_4, KiKit_MB_84_5, KiKit_MB_84_6, KiKit_MB_85_2, KiKit_MB_85_3, KiKit_MB_85_4, KiKit_MB_85_5, KiKit_MB_85_6, KiKit_MB_86_2, KiKit_MB_86_3, KiKit_MB_86_4, KiKit_MB_86_5, KiKit_MB_86_6, KiKit_MB_87_2, KiKit_MB_87_3, KiKit_MB_87_4, KiKit_MB_87_5, KiKit_MB_87_6, KiKit_MB_88_2, KiKit_MB_88_3, KiKit_MB_88_4, KiKit_MB_88_5, KiKit_MB_88_6, KiKit_MB_89_2, KiKit_MB_89_3, KiKit_MB_89_4, KiKit_MB_89_5, KiKit_MB_89_6, KiKit_MB_90_2, KiKit_MB_90_3, KiKit_MB_90_4, KiKit_MB_90_5, KiKit_MB_90_6, KiKit_MB_91_2, KiKit_MB_91_3, KiKit_MB_91_4, KiKit_MB_91_5, KiKit_MB_91_6, KiKit_MB_92_2, KiKit_MB_92_3, KiKit_MB_92_4, KiKit_MB_92_5, KiKit_MB_92_6, KiKit_MB_93_2, KiKit_MB_93_3, KiKit_MB_93_4, KiKit_MB_93_5, KiKit_MB_93_6, KiKit_MB_94_2, KiKit_MB_94_3, KiKit_MB_94_4, KiKit_MB_94_5, KiKit_MB_94_6, KiKit_MB_95_2, KiKit_MB_95_3, KiKit_MB_95_4, KiKit_MB_95_5, KiKit_MB_95_6, KiKit_MB_96_2, KiKit_MB_96_3, KiKit_MB_96_4, KiKit_MB_96_5, KiKit_MB_96_6, KiKit_MB_97_2, KiKit_MB_97_3, KiKit_MB_97_4, KiKit_MB_97_5, KiKit_MB_97_6, KiKit_MB_98_2, KiKit_MB_98_3, KiKit_MB_98_4, KiKit_MB_98_5, KiKit_MB_98_6, KiKit_MB_99_2, KiKit_MB_99_3, KiKit_MB_99_4, KiKit_MB_99_5, KiKit_MB_99_6, KiKit_MB_100_2, KiKit_MB_100_3, KiKit_MB_100_4, KiKit_MB_100_5, KiKit_MB_100_6, KiKit_MB_101_2, KiKit_MB_101_3, KiKit_MB_101_4, KiKit_MB_101_5, KiKit_MB_101_6, KiKit_MB_102_2, KiKit_MB_102_3, KiKit_MB_102_4, KiKit_MB_102_5, KiKit_MB_102_6, KiKit_MB_103_2, KiKit_MB_103_3, KiKit_MB_103_4, KiKit_MB_103_5, KiKit_MB_103_6, KiKit_MB_104_2, KiKit_MB_104_3, KiKit_MB_104_4, KiKit_MB_104_5, KiKit_MB_104_6, KiKit_MB_105_2, KiKit_MB_105_3, KiKit_MB_105_4, KiKit_MB_105_5, KiKit_MB_105_6, KiKit_MB_106_2, KiKit_MB_106_3, KiKit_MB_106_4, KiKit_MB_106_5, KiKit_MB_106_6, KiKit_MB_107_2, KiKit_MB_107_3, KiKit_MB_107_4, KiKit_MB_107_5, KiKit_MB_107_6, KiKit_MB_108_2, KiKit_MB_108_3, KiKit_MB_108_4, KiKit_MB_108_5, KiKit_MB_108_6, KiKit_MB_109_2, KiKit_MB_109_3, KiKit_MB_109_4, KiKit_MB_109_5, KiKit_MB_109_6, KiKit_MB_110_2, KiKit_MB_110_3, KiKit_MB_110_4, KiKit_MB_110_5, KiKit_MB_110_6, KiKit_MB_111_2, KiKit_MB_111_3, KiKit_MB_111_4, KiKit_MB_111_5, KiKit_MB_111_6, KiKit_MB_112_2, KiKit_MB_112_3, KiKit_MB_112_4, KiKit_MB_112_5, KiKit_MB_112_6, KiKit_MB_113_2, KiKit_MB_113_3, KiKit_MB_113_4, KiKit_MB_113_5, KiKit_MB_113_6, KiKit_MB_114_2, KiKit_MB_114_3, KiKit_MB_114_4, KiKit_MB_114_5, KiKit_MB_114_6, KiKit_MB_115_2, KiKit_MB_115_3, KiKit_MB_115_4, KiKit_MB_115_5, KiKit_MB_115_6, KiKit_MB_116_2, KiKit_MB_116_3, KiKit_MB_116_4, KiKit_MB_116_5, KiKit_MB_116_6, KiKit_MB_117_2, KiKit_MB_117_3, KiKit_MB_117_4, KiKit_MB_117_5, KiKit_MB_117_6, KiKit_MB_118_2, KiKit_MB_118_3, KiKit_MB_118_4, KiKit_MB_118_5, KiKit_MB_118_6, KiKit_MB_119_2, KiKit_MB_119_3, KiKit_MB_119_4, KiKit_MB_119_5, KiKit_MB_119_6, KiKit_MB_120_2, KiKit_MB_120_3, KiKit_MB_120_4, KiKit_MB_120_5, KiKit_MB_120_6: NPTH
Q1, Q1#2, Q1#3, Q1#4, Q1#5, Q1#6, Q1#7, Q1#8, Q1#9, Q1#10, Q1#11, Q1#12, Q1#13, Q1#14, Q1#15, Q1#16, Q1#17, Q1#18, Q1#19, Q1#20, Q1#21, Q1#22, Q1#23, Q1#24, Q1#25, Q1#26, Q1#27, Q1#28, Q1#29, Q1#30, Q1#31, Q1#32, Q1#33, Q1#34, Q1#35, Q1#36, Q1#37, Q1#38, Q1#39, Q1#40, Q1#41, Q1#42, Q1#43, Q1#44, Q1#45, Q1#46, Q1#47, Q1#48, Q1#49, Q1#50, Q1#51, Q1#52, Q1#53, Q1#54, Q1#55, Q1#56, Q1#57, Q1#58, Q1#59, Q1#60: BCM847DS; SOT-23-6_Handsoldering

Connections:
Board_0-Net-(J1-Pin_1): J1#17.1, Q1#11.1 (E1)
Board_0-Net-(J1-Pin_2): J1#17.2, Q1#11.2 (B1)
Board_0-Net-(J1-Pin_3): J1#17.3, Q1#11.3 (C2)
Board_0-Net-(J2-Pin_1): J2#59.1, Q1#11.6 (C1)
Board_0-Net-(J2-Pin_2): J2#59.2, Q1#11.5 (B2)
Board_0-Net-(J2-Pin_3): J2#59.3, Q1#11.4 (E2)
Board_1-Net-(J1-Pin_1): J1#7.1, Q1#18.1 (E1)
Board_1-Net-(J1-Pin_2): J1#7.2, Q1#18.2 (B1)
Board_1-Net-(J1-Pin_3): J1#7.3, Q1#18.3 (C2)
Board_1-Net-(J2-Pin_1): J2#15.1, Q1#18.6 (C1)
Board_1-Net-(J2-Pin_2): J2#15.2, Q1#18.5 (B2)
Board_1-Net-(J2-Pin_3): J2#15.3, Q1#18.4 (E2)
Board_2-Net-(J1-Pin_1): J1#5.1, Q1#51.1 (E1)
Board_2-Net-(J1-Pin_2): J1#5.2, Q1#51.2 (B1)
Board_2-Net-(J1-Pin_3): J1#5.3, Q1#51.3 (C2)
Board_2-Net-(J2-Pin_1): J2#28.1, Q1#51.6 (C1)
Board_2-Net-(J2-Pin_2): J2#28.2, Q1#51.5 (B2)
Board_2-Net-(J2-Pin_3): J2#28.3, Q1#51.4 (E2)
Board_3-Net-(J1-Pin_1): J1#29.1, Q1#7.1 (E1)
Board_3-Net-(J1-Pin_2): J1#29.2, Q1#7.2 (B1)
Board_3-Net-(J1-Pin_3): J1#29.3, Q1#7.3 (C2)
Board_3-Net-(J2-Pin_1): J2#50.1, Q1#7.6 (C1)
Board_3-Net-(J2-Pin_2): J2#50.2, Q1#7.5 (B2)
Board_3-Net-(J2-Pin_3): J2#50.3, Q1#7.4 (E2)
Board_4-Net-(J1-Pin_1): J1#21.1, Q1.1 (E1)
Board_4-Net-(J1-Pin_2): J1#21.2, Q1.2 (B1)
Board_4-Net-(J1-Pin_3): J1#21.3, Q1.3 (C2)
Board_4-Net-(J2-Pin_1): J2#4.1, Q1.6 (C1)
Board_4-Net-(J2-Pin_2): J2#4.2, Q1.5 (B2)
Board_4-Net-(J2-Pin_3): J2#4.3, Q1.4 (E2)
Board_5-Net-(J1-Pin_1): J1#3.1, Q1#6.1 (E1)
Board_5-Net-(J1-Pin_2): J1#3.2, Q1#6.2 (B1)
Board_5-Net-(J1-Pin_3): J1#3.3, Q1#6.3 (C2)
Board_5-Net-(J2-Pin_1): J2#33.1, Q1#6.6 (C1)
Board_5-Net-(J2-Pin_2): J2#33.2, Q1#6.5 (B2)
Board_5-Net-(J2-Pin_3): J2#33.3, Q1#6.4 (E2)
Board_6-Net-(J1-Pin_1): J1#14.1, Q1#57.1 (E1)
Board_6-Net-(J1-Pin_2): J1#14.2, Q1#57.2 (B1)
Board_6-Net-(J1-Pin_3): J1#14.3, Q1#57.3 (C2)
Board_6-Net-(J2-Pin_1): J2#31.1, Q1#57.6 (C1)
Board_6-Net-(J2-Pin_2): J2#31.2, Q1#57.5 (B2)
Board_6-Net-(J2-Pin_3): J2#31.3, Q1#57.4 (E2)
Board_7-Net-(J1-Pin_1): J1#37.1, Q1#50.1 (E1)
Board_7-Net-(J1-Pin_2): J1#37.2, Q1#50.2 (B1)
Board_7-Net-(J1-Pin_3): J1#37.3, Q1#50.3 (C2)
Board_7-Net-(J2-Pin_1): J2#44.1, Q1#50.6 (C1)
Board_7-Net-(J2-Pin_2): J2#44.2, Q1#50.5 (B2)
Board_7-Net-(J2-Pin_3): J2#44.3, Q1#50.4 (E2)
Board_8-Net-(J1-Pin_1): J1#26.1, Q1#58.1 (E1)
Board_8-Net-(J1-Pin_2): J1#26.2, Q1#58.2 (B1)
Board_8-Net-(J1-Pin_3): J1#26.3, Q1#58.3 (C2)
Board_8-Net-(J2-Pin_1): J2#22.1, Q1#58.6 (C1)
Board_8-Net-(J2-Pin_2): J2#22.2, Q1#58.5 (B2)
Board_8-Net-(J2-Pin_3): J2#22.3, Q1#58.4 (E2)
Board_9-Net-(J1-Pin_1): J1#22.1, Q1#53.1 (E1)
Board_9-Net-(J1-Pin_2): J1#22.2, Q1#53.2 (B1)
Board_9-Net-(J1-Pin_3): J1#22.3, Q1#53.3 (C2)
Board_9-Net-(J2-Pin_1): J2#12.1, Q1#53.6 (C1)
Board_9-Net-(J2-Pin_2): J2#12.2, Q1#53.5 (B2)
Board_9-Net-(J2-Pin_3): J2#12.3, Q1#53.4 (E2)
Board_10-Net-(J1-Pin_1): J1#2.1, Q1#5.1 (E1)
Board_10-Net-(J1-Pin_2): J1#2.2, Q1#5.2 (B1)
Board_10-Net-(J1-Pin_3): J1#2.3, Q1#5.3 (C2)
Board_10-Net-(J2-Pin_1): J2#48.1, Q1#5.6 (C1)
Board_10-Net-(J2-Pin_2): J2#48.2, Q1#5.5 (B2)
Board_10-Net-(J2-Pin_3): J2#48.3, Q1#5.4 (E2)
Board_11-Net-(J1-Pin_1): J1#35.1, Q1#28.1 (E1)
Board_11-Net-(J1-Pin_2): J1#35.2, Q1#28.2 (B1)
Board_11-Net-(J1-Pin_3): J1#35.3, Q1#28.3 (C2)
Board_11-Net-(J2-Pin_1): J2#23.1, Q1#28.6 (C1)
Board_11-Net-(J2-Pin_2): J2#23.2, Q1#28.5 (B2)
Board_11-Net-(J2-Pin_3): J2#23.3, Q1#28.4 (E2)
Board_12-Net-(J1-Pin_1): J1#32.1, Q1#33.1 (E1)
Board_12-Net-(J1-Pin_2): J1#32.2, Q1#33.2 (B1)
Board_12-Net-(J1-Pin_3): J1#32.3, Q1#33.3 (C2)
Board_12-Net-(J2-Pin_1): J2#19.1, Q1#33.6 (C1)
Board_12-Net-(J2-Pin_2): J2#19.2, Q1#33.5 (B2)
Board_12-Net-(J2-Pin_3): J2#19.3, Q1#33.4 (E2)
Board_13-Net-(J1-Pin_1): J1#56.1, Q1#9.1 (E1)
Board_13-Net-(J1-Pin_2): J1#56.2, Q1#9.2 (B1)
Board_13-Net-(J1-Pin_3): J1#56.3, Q1#9.3 (C2)
Board_13-Net-(J2-Pin_1): J2#17.1, Q1#9.6 (C1)
Board_13-Net-(J2-Pin_2): J2#17.2, Q1#9.5 (B2)
Board_13-Net-(J2-Pin_3): J2#17.3, Q1#9.4 (E2)
Board_14-Net-(J1-Pin_1): J1#16.1, Q1#42.1 (E1)
Board_14-Net-(J1-Pin_2): J1#16.2, Q1#42.2 (B1)
Board_14-Net-(J1-Pin_3): J1#16.3, Q1#42.3 (C2)
Board_14-Net-(J2-Pin_1): J2#57.1, Q1#42.6 (C1)
Board_14-Net-(J2-Pin_2): J2#57.2, Q1#42.5 (B2)
Board_14-Net-(J2-Pin_3): J2#57.3, Q1#42.4 (E2)
Board_15-Net-(J1-Pin_1): J1#43.1, Q1#26.1 (E1)
Board_15-Net-(J1-Pin_2): J1#43.2, Q1#26.2 (B1)
Board_15-Net-(J1-Pin_3): J1#43.3, Q1#26.3 (C2)
Board_15-Net-(J2-Pin_1): J2#35.1, Q1#26.6 (C1)
Board_15-Net-(J2-Pin_2): J2#35.2, Q1#26.5 (B2)
Board_15-Net-(J2-Pin_3): J2#35.3, Q1#26.4 (E2)
Board_16-Net-(J1-Pin_1): J1#41.1, Q1#4.1 (E1)
Board_16-Net-(J1-Pin_2): J1#41.2, Q1#4.2 (B1)
Board_16-Net-(J1-Pin_3): J1#41.3, Q1#4.3 (C2)
Board_16-Net-(J2-Pin_1): J2#2.1, Q1#4.6 (C1)
Board_16-Net-(J2-Pin_2): J2#2.2, Q1#4.5 (B2)
Board_16-Net-(J2-Pin_3): J2#2.3, Q1#4.4 (E2)
Board_17-Net-(J1-Pin_1): J1#40.1, Q1#25.1 (E1)
Board_17-Net-(J1-Pin_2): J1#40.2, Q1#25.2 (B1)
Board_17-Net-(J1-Pin_3): J1#40.3, Q1#25.3 (C2)
Board_17-Net-(J2-Pin_1): J2.1, Q1#25.6 (C1)
Board_17-Net-(J2-Pin_2): J2.2, Q1#25.5 (B2)
Board_17-Net-(J2-Pin_3): J2.3, Q1#25.4 (E2)
Board_18-Net-(J1-Pin_1): J1#50.1, Q1#14.1 (E1)
Board_18-Net-(J1-Pin_2): J1#50.2, Q1#14.2 (B1)
Board_18-Net-(J1-Pin_3): J1#50.3, Q1#14.3 (C2)
Board_18-Net-(J2-Pin_1): J2#13.1, Q1#14.6 (C1)
Board_18-Net-(J2-Pin_2): J2#13.2, Q1#14.5 (B2)
Board_18-Net-(J2-Pin_3): J2#13.3, Q1#14.4 (E2)
Board_19-Net-(J1-Pin_1): J1#49.1, Q1#54.1 (E1)
Board_19-Net-(J1-Pin_2): J1#49.2, Q1#54.2 (B1)
Board_19-Net-(J1-Pin_3): J1#49.3, Q1#54.3 (C2)
Board_19-Net-(J2-Pin_1): J2#34.1, Q1#54.6 (C1)
Board_19-Net-(J2-Pin_2): J2#34.2, Q1#54.5 (B2)
Board_19-Net-(J2-Pin_3): J2#34.3, Q1#54.4 (E2)
Board_20-Net-(J1-Pin_1): J1#46.1, Q1#30.1 (E1)
Board_20-Net-(J1-Pin_2): J1#46.2, Q1#30.2 (B1)
Board_20-Net-(J1-Pin_3): J1#46.3, Q1#30.3 (C2)
Board_20-Net-(J2-Pin_1): J2#60.1, Q1#30.6 (C1)
Board_20-Net-(J2-Pin_2): J2#60.2, Q1#30.5 (B2)
Board_20-Net-(J2-Pin_3): J2#60.3, Q1#30.4 (E2)
Board_21-Net-(J1-Pin_1): J1#48.1, Q1#60.1 (E1)
Board_21-Net-(J1-Pin_2): J1#48.2, Q1#60.2 (B1)
Board_21-Net-(J1-Pin_3): J1#48.3, Q1#60.3 (C2)
Board_21-Net-(J2-Pin_1): J2#40.1, Q1#60.6 (C1)
Board_21-Net-(J2-Pin_2): J2#40.2, Q1#60.5 (B2)
Board_21-Net-(J2-Pin_3): J2#40.3, Q1#60.4 (E2)
Board_22-Net-(J1-Pin_1): J1#58.1, Q1#49.1 (E1)
Board_22-Net-(J1-Pin_2): J1#58.2, Q1#49.2 (B1)
Board_22-Net-(J1-Pin_3): J1#58.3, Q1#49.3 (C2)
Board_22-Net-(J2-Pin_1): J2#10.1, Q1#49.6 (C1)
Board_22-Net-(J2-Pin_2): J2#10.2, Q1#49.5 (B2)
Board_22-Net-(J2-Pin_3): J2#10.3, Q1#49.4 (E2)
Board_23-Net-(J1-Pin_1): J1#15.1, Q1#44.1 (E1)
Board_23-Net-(J1-Pin_2): J1#15.2, Q1#44.2 (B1)
Board_23-Net-(J1-Pin_3): J1#15.3, Q1#44.3 (C2)
Board_23-Net-(J2-Pin_1): J2#7.1, Q1#44.6 (C1)
Board_23-Net-(J2-Pin_2): J2#7.2, Q1#44.5 (B2)
Board_23-Net-(J2-Pin_3): J2#7.3, Q1#44.4 (E2)
Board_24-Net-(J1-Pin_1): J1#20.1, Q1#23.1 (E1)
Board_24-Net-(J1-Pin_2): J1#20.2, Q1#23.2 (B1)
Board_24-Net-(J1-Pin_3): J1#20.3, Q1#23.3 (C2)
Board_24-Net-(J2-Pin_1): J2#24.1, Q1#23.6 (C1)
Board_24-Net-(J2-Pin_2): J2#24.2, Q1#23.5 (B2)
Board_24-Net-(J2-Pin_3): J2#24.3, Q1#23.4 (E2)
Board_25-Net-(J1-Pin_1): J1#19.1, Q1#22.1 (E1)
Board_25-Net-(J1-Pin_2): J1#19.2, Q1#22.2 (B1)
Board_25-Net-(J1-Pin_3): J1#19.3, Q1#22.3 (C2)
Board_25-Net-(J2-Pin_1): J2#39.1, Q1#22.6 (C1)
Board_25-Net-(J2-Pin_2): J2#39.2, Q1#22.5 (B2)
Board_25-Net-(J2-Pin_3): J2#39.3, Q1#22.4 (E2)
Board_26-Net-(J1-Pin_1): J1#31.1, Q1#56.1 (E1)
Board_26-Net-(J1-Pin_2): J1#31.2, Q1#56.2 (B1)
Board_26-Net-(J1-Pin_3): J1#31.3, Q1#56.3 (C2)
Board_26-Net-(J2-Pin_1): J2#58.1, Q1#56.6 (C1)
Board_26-Net-(J2-Pin_2): J2#58.2, Q1#56.5 (B2)
Board_26-Net-(J2-Pin_3): J2#58.3, Q1#56.4 (E2)
Board_27-Net-(J1-Pin_1): J1#33.1, Q1#40.1 (E1)
Board_27-Net-(J1-Pin_2): J1#33.2, Q1#40.2 (B1)
Board_27-Net-(J1-Pin_3): J1#33.3, Q1#40.3 (C2)
Board_27-Net-(J2-Pin_1): J2#49.1, Q1#40.6 (C1)
Board_27-Net-(J2-Pin_2): J2#49.2, Q1#40.5 (B2)
Board_27-Net-(J2-Pin_3): J2#49.3, Q1#40.4 (E2)
Board_28-Net-(J1-Pin_1): J1#30.1, Q1#19.1 (E1)
Board_28-Net-(J1-Pin_2): J1#30.2, Q1#19.2 (B1)
Board_28-Net-(J1-Pin_3): J1#30.3, Q1#19.3 (C2)
Board_28-Net-(J2-Pin_1): J2#42.1, Q1#19.6 (C1)
Board_28-Net-(J2-Pin_2): J2#42.2, Q1#19.5 (B2)
Board_28-Net-(J2-Pin_3): J2#42.3, Q1#19.4 (E2)
Board_29-Net-(J1-Pin_1): J1#18.1, Q1#24.1 (E1)
Board_29-Net-(J1-Pin_2): J1#18.2, Q1#24.2 (B1)
Board_29-Net-(J1-Pin_3): J1#18.3, Q1#24.3 (C2)
Board_29-Net-(J2-Pin_1): J2#5.1, Q1#24.6 (C1)
Board_29-Net-(J2-Pin_2): J2#5.2, Q1#24.5 (B2)
Board_29-Net-(J2-Pin_3): J2#5.3, Q1#24.4 (E2)
Board_30-Net-(J1-Pin_1): J1#57.1, Q1#35.1 (E1)
Board_30-Net-(J1-Pin_2): J1#57.2, Q1#35.2 (B1)
Board_30-Net-(J1-Pin_3): J1#57.3, Q1#35.3 (C2)
Board_30-Net-(J2-Pin_1): J2#53.1, Q1#35.6 (C1)
Board_30-Net-(J2-Pin_2): J2#53.2, Q1#35.5 (B2)
Board_30-Net-(J2-Pin_3): J2#53.3, Q1#35.4 (E2)
Board_31-Net-(J1-Pin_1): J1#52.1, Q1#55.1 (E1)
Board_31-Net-(J1-Pin_2): J1#52.2, Q1#55.2 (B1)
Board_31-Net-(J1-Pin_3): J1#52.3, Q1#55.3 (C2)
Board_31-Net-(J2-Pin_1): J2#41.1, Q1#55.6 (C1)
Board_31-Net-(J2-Pin_2): J2#41.2, Q1#55.5 (B2)
Board_31-Net-(J2-Pin_3): J2#41.3, Q1#55.4 (E2)
Board_32-Net-(J1-Pin_1): J1#11.1, Q1#3.1 (E1)
Board_32-Net-(J1-Pin_2): J1#11.2, Q1#3.2 (B1)
Board_32-Net-(J1-Pin_3): J1#11.3, Q1#3.3 (C2)
Board_32-Net-(J2-Pin_1): J2#46.1, Q1#3.6 (C1)
Board_32-Net-(J2-Pin_2): J2#46.2, Q1#3.5 (B2)
Board_32-Net-(J2-Pin_3): J2#46.3, Q1#3.4 (E2)
Board_33-Net-(J1-Pin_1): J1#13.1, Q1#27.1 (E1)
Board_33-Net-(J1-Pin_2): J1#13.2, Q1#27.2 (B1)
Board_33-Net-(J1-Pin_3): J1#13.3, Q1#27.3 (C2)
Board_33-Net-(J2-Pin_1): J2#51.1, Q1#27.6 (C1)
Board_33-Net-(J2-Pin_2): J2#51.2, Q1#27.5 (B2)
Board_33-Net-(J2-Pin_3): J2#51.3, Q1#27.4 (E2)
Board_34-Net-(J1-Pin_1): J1#25.1, Q1#34.1 (E1)
Board_34-Net-(J1-Pin_2): J1#25.2, Q1#34.2 (B1)
Board_34-Net-(J1-Pin_3): J1#25.3, Q1#34.3 (C2)
Board_34-Net-(J2-Pin_1): J2#47.1, Q1#34.6 (C1)
Board_34-Net-(J2-Pin_2): J2#47.2, Q1#34.5 (B2)
Board_34-Net-(J2-Pin_3): J2#47.3, Q1#34.4 (E2)
Board_35-Net-(J1-Pin_1): J1#4.1, Q1#20.1 (E1)
Board_35-Net-(J1-Pin_2): J1#4.2, Q1#20.2 (B1)
Board_35-Net-(J1-Pin_3): J1#4.3, Q1#20.3 (C2)
Board_35-Net-(J2-Pin_1): J2#27.1, Q1#20.6 (C1)
Board_35-Net-(J2-Pin_2): J2#27.2, Q1#20.5 (B2)
Board_35-Net-(J2-Pin_3): J2#27.3, Q1#20.4 (E2)
Board_36-Net-(J1-Pin_1): J1#39.1, Q1#37.1 (E1)
Board_36-Net-(J1-Pin_2): J1#39.2, Q1#37.2 (B1)
Board_36-Net-(J1-Pin_3): J1#39.3, Q1#37.3 (C2)
Board_36-Net-(J2-Pin_1): J2#6.1, Q1#37.6 (C1)
Board_36-Net-(J2-Pin_2): J2#6.2, Q1#37.5 (B2)
Board_36-Net-(J2-Pin_3): J2#6.3, Q1#37.4 (E2)
Board_37-Net-(J1-Pin_1): J1#42.1, Q1#32.1 (E1)
Board_37-Net-(J1-Pin_2): J1#42.2, Q1#32.2 (B1)
Board_37-Net-(J1-Pin_3): J1#42.3, Q1#32.3 (C2)
Board_37-Net-(J2-Pin_1): J2#11.1, Q1#32.6 (C1)
Board_37-Net-(J2-Pin_2): J2#11.2, Q1#32.5 (B2)
Board_37-Net-(J2-Pin_3): J2#11.3, Q1#32.4 (E2)
Board_38-Net-(J1-Pin_1): J1#51.1, Q1#43.1 (E1)
Board_38-Net-(J1-Pin_2): J1#51.2, Q1#43.2 (B1)
Board_38-Net-(J1-Pin_3): J1#51.3, Q1#43.3 (C2)
Board_38-Net-(J2-Pin_1): J2#45.1, Q1#43.6 (C1)
Board_38-Net-(J2-Pin_2): J2#45.2, Q1#43.5 (B2)
Board_38-Net-(J2-Pin_3): J2#45.3, Q1#43.4 (E2)
Board_39-Net-(J1-Pin_1): J1#24.1, Q1#48.1 (E1)
Board_39-Net-(J1-Pin_2): J1#24.2, Q1#48.2 (B1)
Board_39-Net-(J1-Pin_3): J1#24.3, Q1#48.3 (C2)
Board_39-Net-(J2-Pin_1): J2#16.1, Q1#48.6 (C1)
Board_39-Net-(J2-Pin_2): J2#16.2, Q1#48.5 (B2)
Board_39-Net-(J2-Pin_3): J2#16.3, Q1#48.4 (E2)
Board_40-Net-(J1-Pin_1): J1#44.1, Q1#16.1 (E1)
Board_40-Net-(J1-Pin_2): J1#44.2, Q1#16.2 (B1)
Board_40-Net-(J1-Pin_3): J1#44.3, Q1#16.3 (C2)
Board_40-Net-(J2-Pin_1): J2#3.1, Q1#16.6 (C1)
Board_40-Net-(J2-Pin_2): J2#3.2, Q1#16.5 (B2)
Board_40-Net-(J2-Pin_3): J2#3.3, Q1#16.4 (E2)
Board_41-Net-(J1-Pin_1): J1#6.1, Q1#13.1 (E1)
Board_41-Net-(J1-Pin_2): J1#6.2, Q1#13.2 (B1)
Board_41-Net-(J1-Pin_3): J1#6.3, Q1#13.3 (C2)
Board_41-Net-(J2-Pin_1): J2#14.1, Q1#13.6 (C1)
Board_41-Net-(J2-Pin_2): J2#14.2, Q1#13.5 (B2)
Board_41-Net-(J2-Pin_3): J2#14.3, Q1#13.4 (E2)
Board_42-Net-(J1-Pin_1): J1#8.1, Q1#46.1 (E1)
Board_42-Net-(J1-Pin_2): J1#8.2, Q1#46.2 (B1)
Board_42-Net-(J1-Pin_3): J1#8.3, Q1#46.3 (C2)
Board_42-Net-(J2-Pin_1): J2#18.1, Q1#46.6 (C1)
Board_42-Net-(J2-Pin_2): J2#18.2, Q1#46.5 (B2)
Board_42-Net-(J2-Pin_3): J2#18.3, Q1#46.4 (E2)
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

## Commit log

2026-02-18 Add SOIC.
    [soic breakouts-B_Cu.gbl, soic breakouts-B_Mask.gbs, soic breakouts-B_Paste.gbp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]
2026-02-18 Add SOT-23.
    [sot-23-8-breakout.kicad_pcb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]
2026-02-18 Add SOIC-DW
    [soic-dw-panel.kicad_pcb, soic-dw.kicad_pcb, soic-dw.kicad_sch]
2026-02-18 Add QFN-20 and micromatch-20.
    [micromatch-20-breakout-B_Cu.gbl, micromatch-20-breakout-B_Mask.gbs, micromatch-20-breakout-B_Paste.gbp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]
2026-02-18 Add SOIC-DW RTM v1 gerbers.
    [soic-dw-panel-B_Cu.gbl, soic-dw-panel-B_Mask.gbs, soic-dw-panel-B_Paste.gbp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]
2026-02-18 Add QFN-20 RTM gerbers.
    [qfn-20-breakout-B_Cu.gbl, qfn-20-breakout-B_Mask.gbs, qfn-20-breakout-B_Paste.gbp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]
2026-05-08 Add SO-8-FET footprint panel.
    [so-8-fet-panelized-B_Cu.gbl, so-8-fet-panelized-B_Mask.gbs, so-8-fet-panelized-B_Paste.gbp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]
